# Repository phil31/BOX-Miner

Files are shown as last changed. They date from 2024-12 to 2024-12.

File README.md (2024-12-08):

## BOX Miner

#### The EKO-Miner is a stackable and rackable ASIC Bitcoin miner that utilizes hashcards. The hashcards are capable of mining Bitcoin by themselves or multiple. The concept of hashcards is highly scalable and offers a clean and streamlined approach to Bitcoin mining.

Miner Box Supports up to 3 ASIC Hashcards. An ATX PSU is required.

- Rackable miner boards based on specifics ASIC Hashboards, generic power supply and driven by an ESP32
- WIFI and ETHERNET connectivity
- TFT RGB LCD 172x320 display
- External standard ATX power supply
- Watercooling for quiet operation
- enclosure box dimensions: 200 x 200 x 140 mm

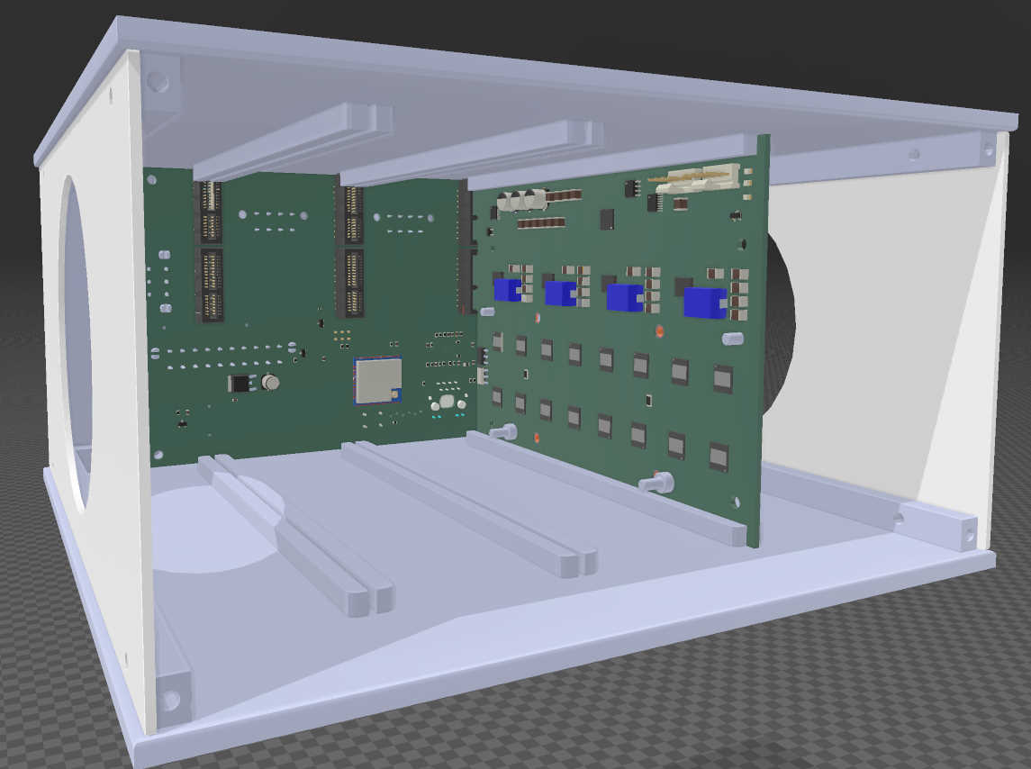
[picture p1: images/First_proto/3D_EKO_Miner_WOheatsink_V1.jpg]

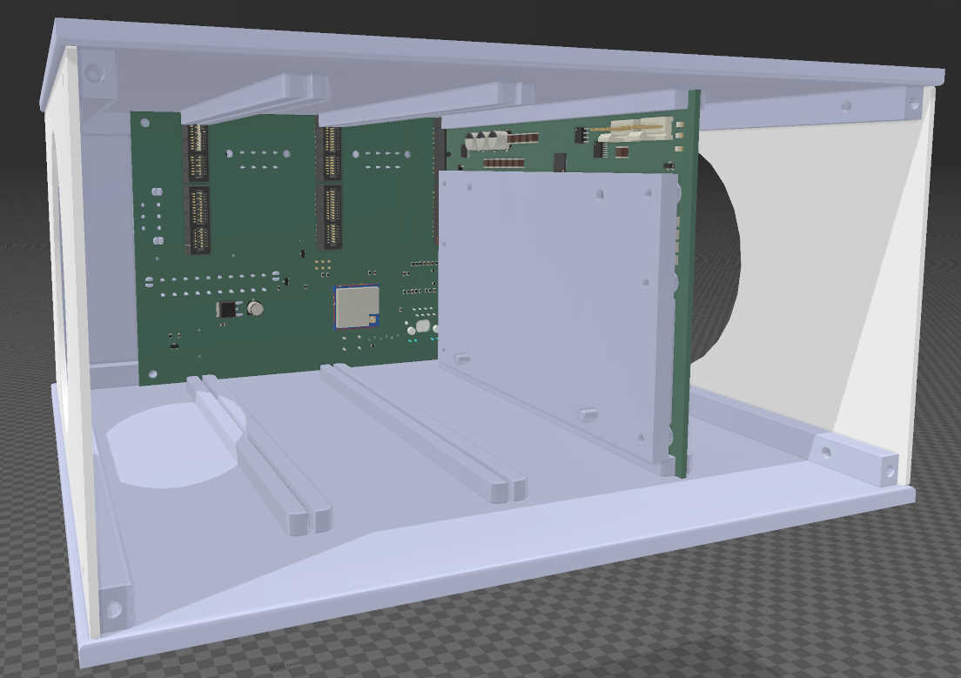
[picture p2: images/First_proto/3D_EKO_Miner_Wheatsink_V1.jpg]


#### Power board : 
- designed with TPS53667 / 5 Phases / 0.5 to 2.5V, up to 380Watts
- 6 layers PCB - Outer / Inner Copper Weight: 2 oz

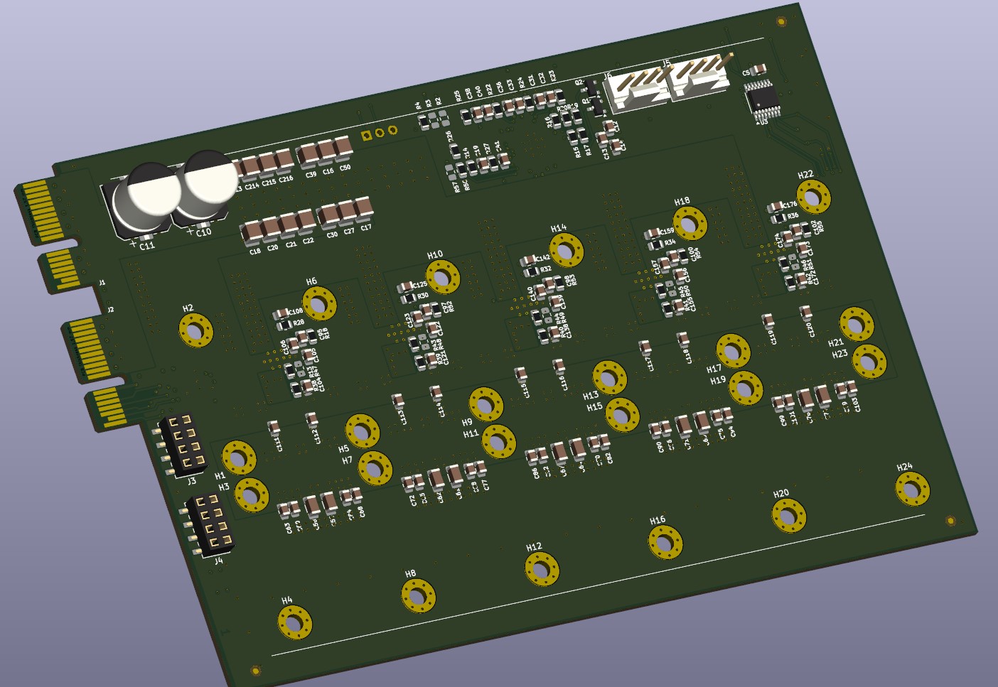
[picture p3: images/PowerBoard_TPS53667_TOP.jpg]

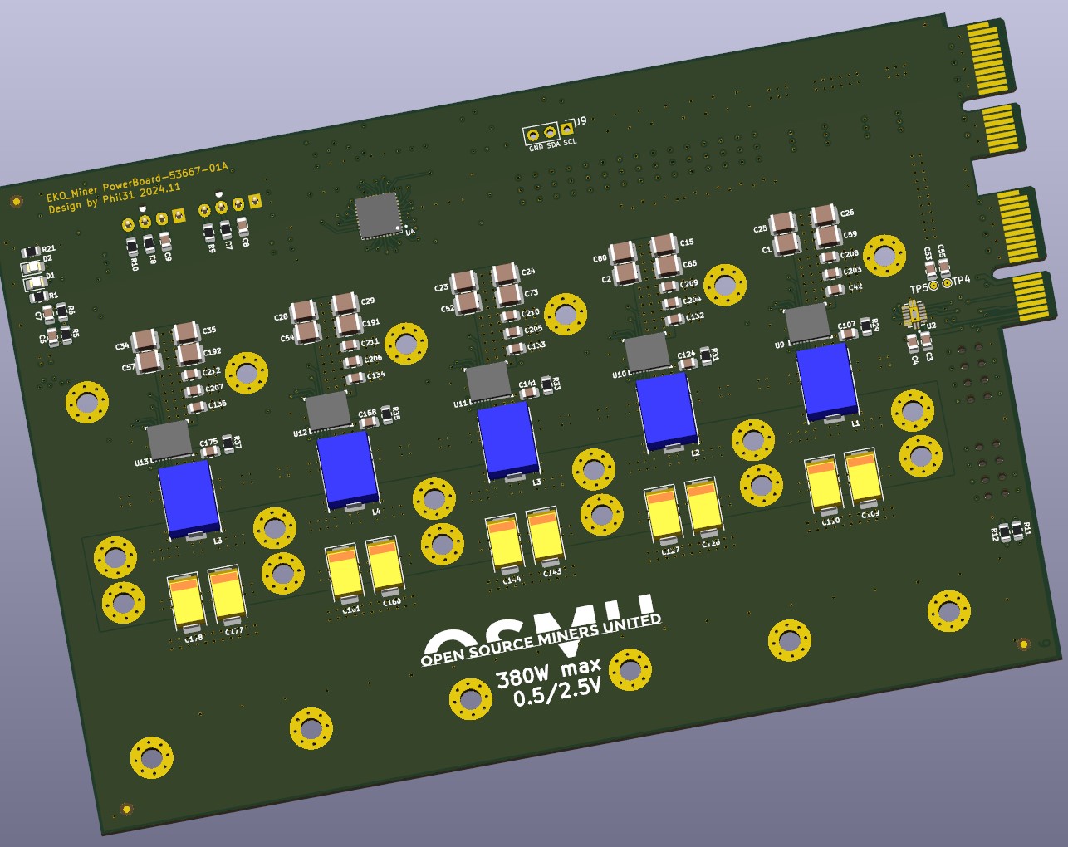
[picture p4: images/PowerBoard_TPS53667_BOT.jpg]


#### AsicBoards : 
- 16 x BM1366 : 8 TH/s - Efficiency 25J/TH
- 16 x BM1368 : 9.5 TH/s - Efficiency 18J/TH
- 10 x BM1370 : 12 TH/s - Efficiency 15J/TH

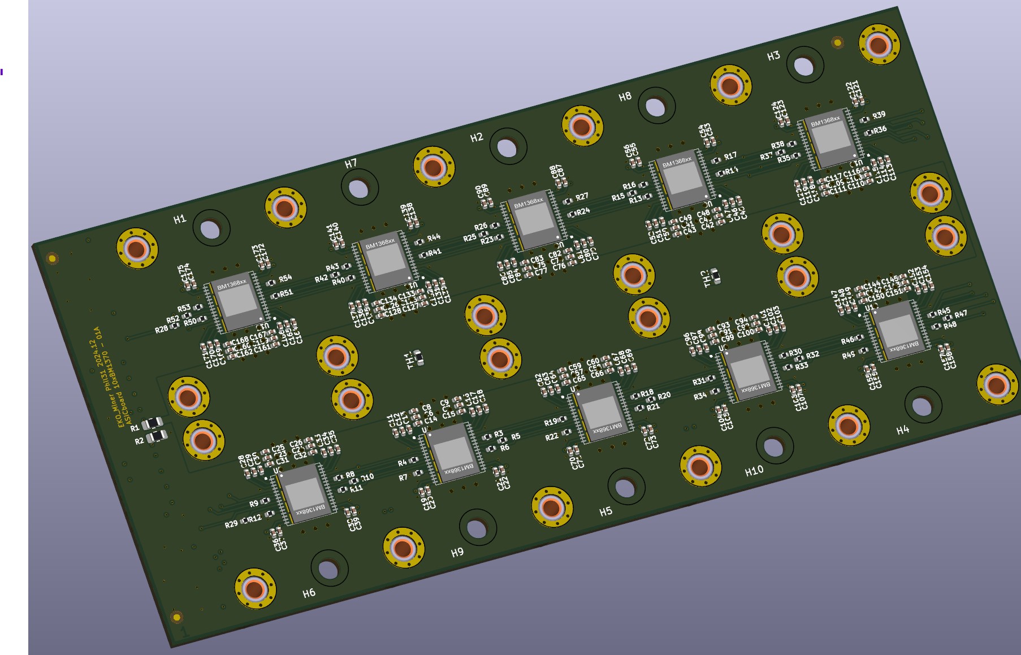
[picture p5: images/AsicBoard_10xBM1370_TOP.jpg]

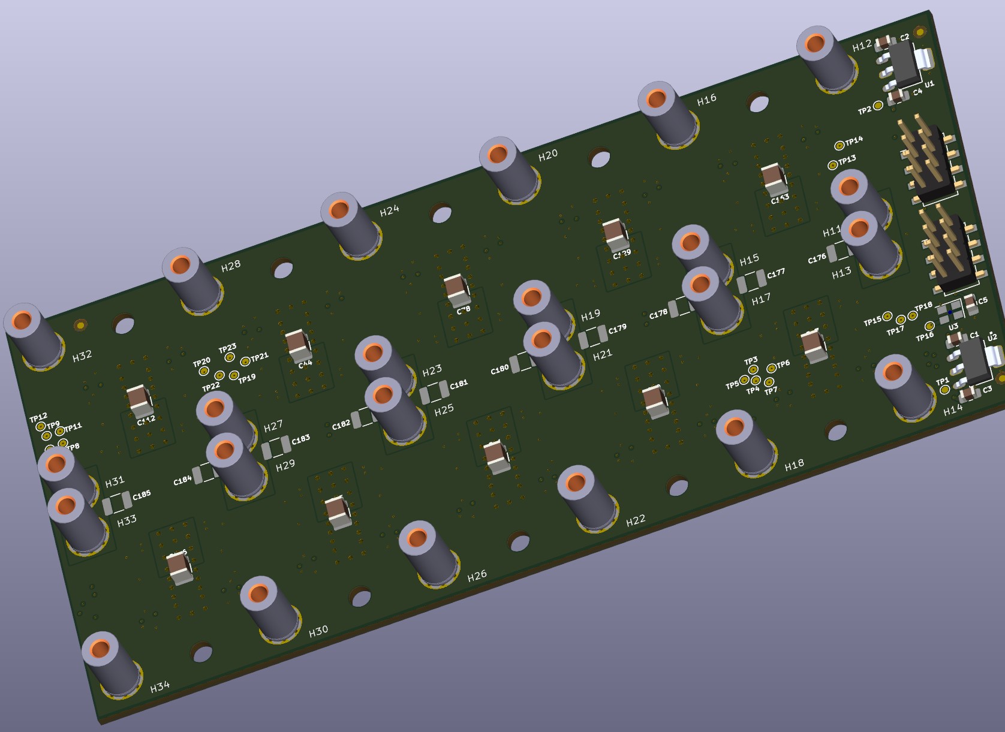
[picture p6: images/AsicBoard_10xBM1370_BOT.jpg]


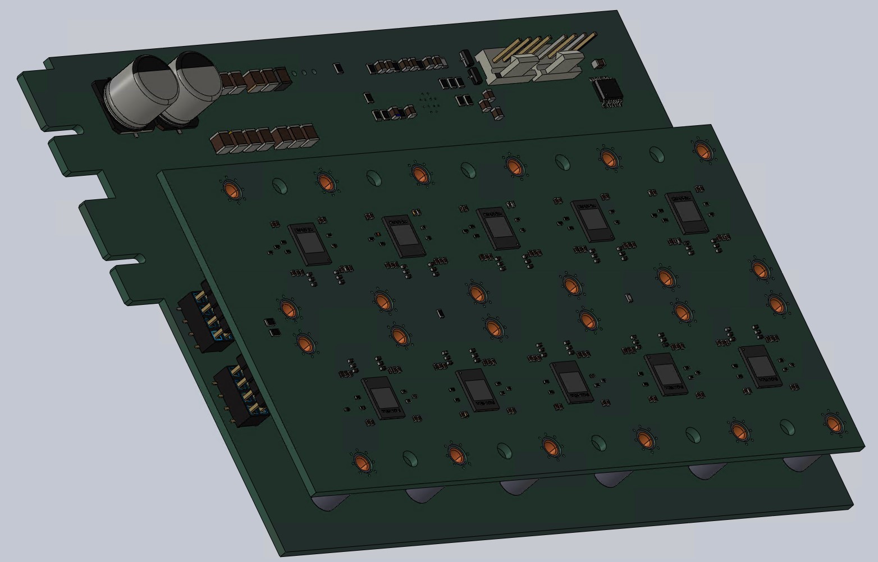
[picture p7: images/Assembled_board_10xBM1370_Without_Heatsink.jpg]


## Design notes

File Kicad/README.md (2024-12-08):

## BOX Miner

#### The EKO-Miner is a stackable and rackable ASIC Bitcoin miner that utilizes hashcards. The hashcards are capable of mining Bitcoin by themselves or multiple. The concept of hashcards is highly scalable and offers a clean and streamlined approach to Bitcoin mining.

#### 2024-12-07 : Theses boards are currently being validated

Power board : 
- designed with TPS53667 / 5 Phases / 0.5 to 2.5V, up to 300Watts

AsicBoards : 
- 16 x BM1366 : 8 TH/s - Efficiency 25J/TH
- 16 x BM1368 : 9.5 TH/s - Efficiency 18J/TH
- 10 x BM1370 : 10 TH/s - Efficiency 15J/TH

hashcard
hashcard
hashcard
hashcard
hashcard
hashcard

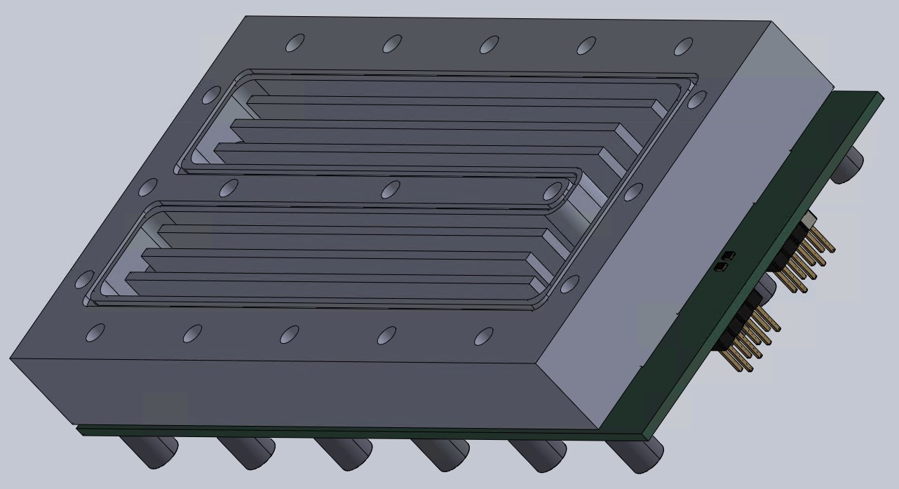
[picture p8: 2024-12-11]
3D/EKO_Miner Box AsicBoard/images/AsicBoard_10xBM1370_with_Watercooling3.jpg

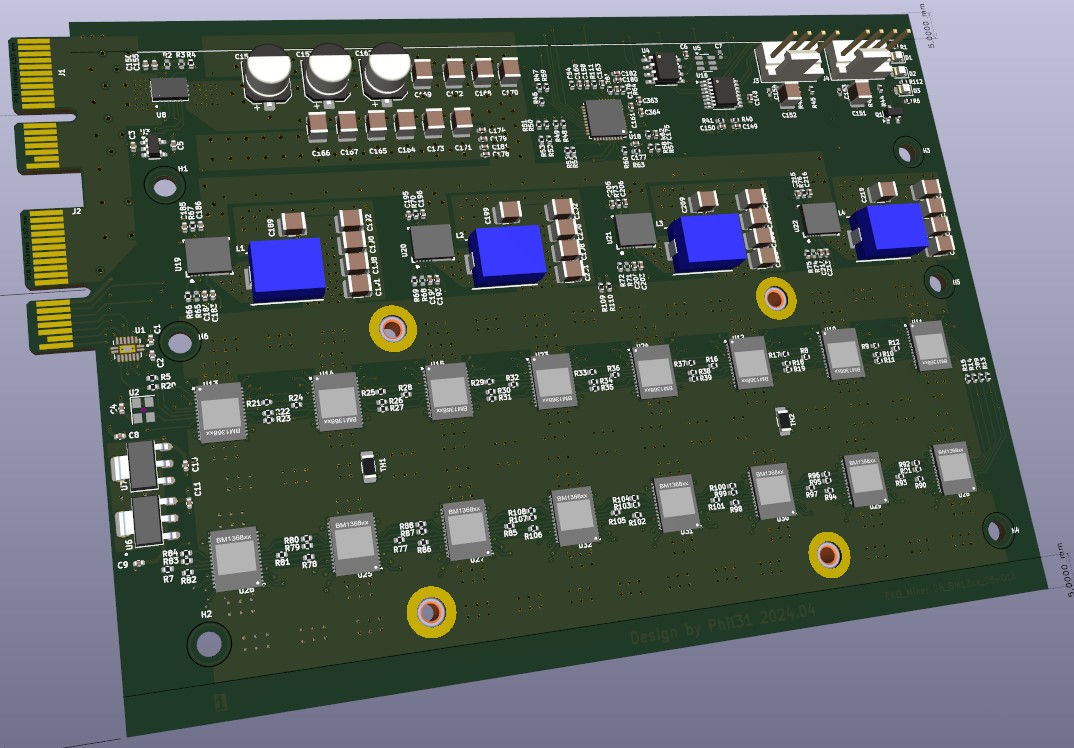
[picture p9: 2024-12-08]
images/First_proto/First_Proto_16xBM1366 T 3D.jpg

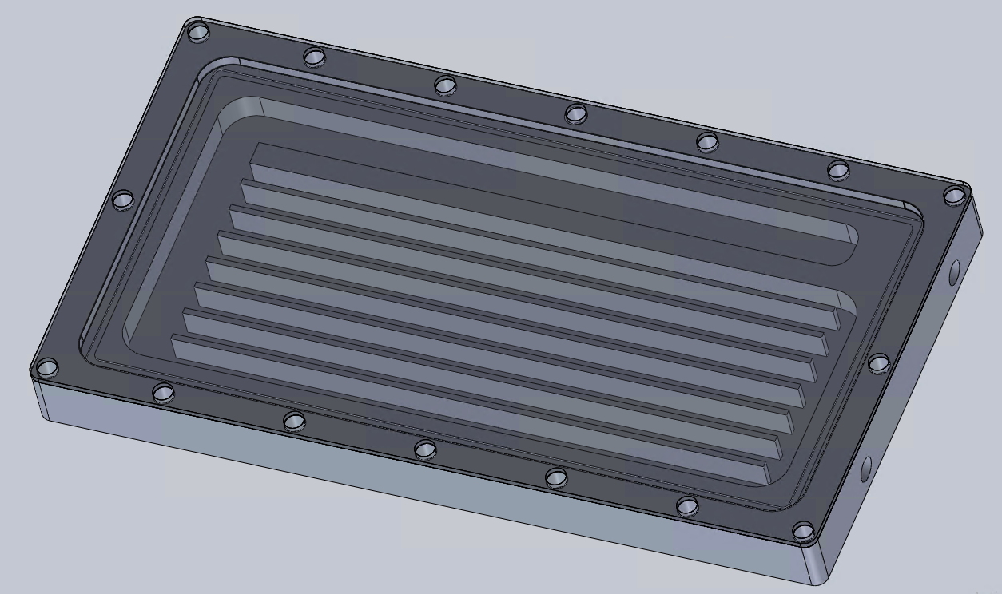
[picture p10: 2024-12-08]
images/WaterBloack_draft.png

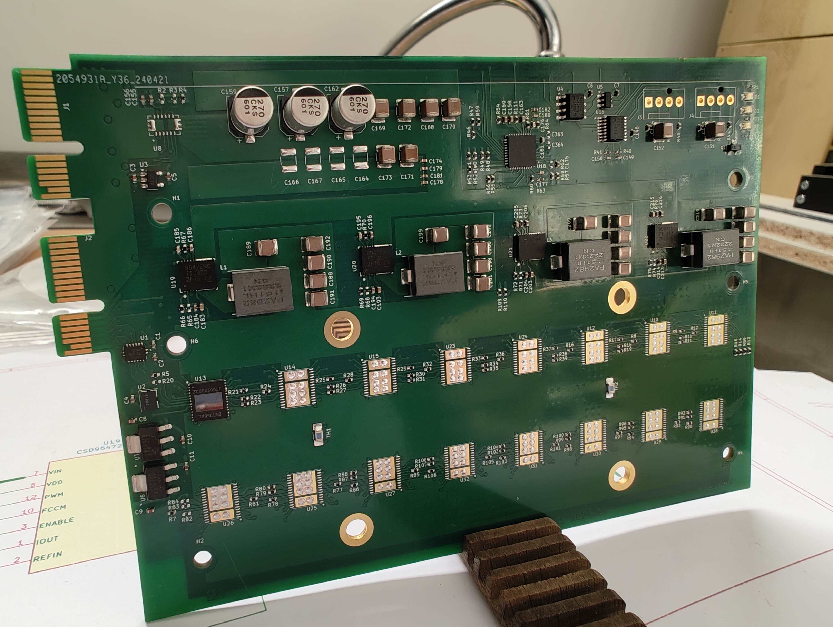
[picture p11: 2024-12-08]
images/First_proto/First_Proto_16xBM1366.jpg

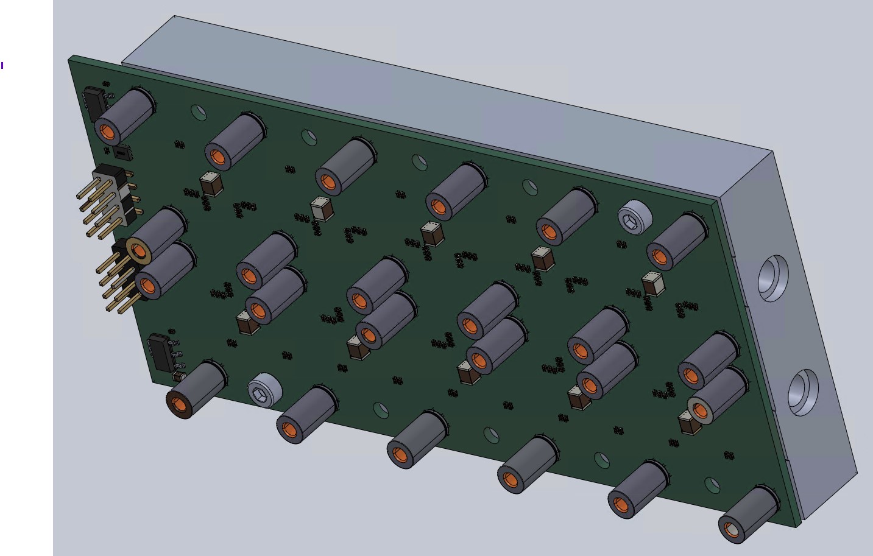
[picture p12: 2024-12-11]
3D/EKO_Miner Box AsicBoard/images/AsicBoard_10xBM1370_with_Watercooling2.jpg

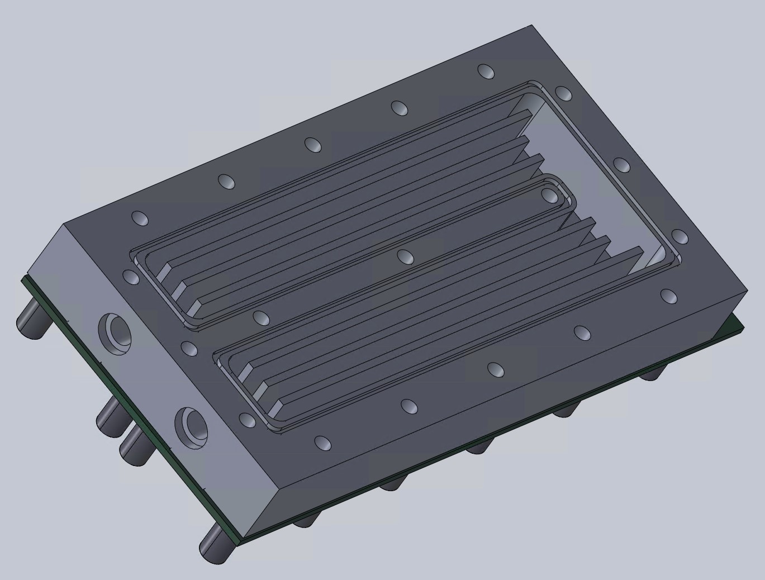
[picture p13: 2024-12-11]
3D/EKO_Miner Box AsicBoard/images/AsicBoard_10xBM1370_with_Watercooling.jpg

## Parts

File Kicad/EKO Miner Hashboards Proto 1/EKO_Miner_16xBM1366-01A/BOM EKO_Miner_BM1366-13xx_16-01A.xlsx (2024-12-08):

ligne | References | Empreinte | Quantité | designation | Fournisseur et rÃ©f
1 | R99,R10,R78,R27,R80,R12,R39,R8,R105,R37,R19,R107,R32,R91,R101,R104,R92,R26,R34,R9,R25,R98,R103,R83,R88,R18,R82,R38,R30,R96,R94,R33,R31,R108,R29,R13,R24,R95,R17,R93,R90,R77,R15,R16,R85,R23,R87,R100,R89,R102,R86,R79,R14,R11,R21,R84,R81,R22,R106,R97,R36,R28,R20,R35 | R_0402_1005Metric | 64 | 33 | 667-ERJ-2RKF33R0X | ok
2 | U19,U21,U20,U22 | CSD95472Q5MC | 4 | CSD95472Q5MC | 595-CSD95472Q5MC | ok
3 | C151,C172,C170,C168,C169,C173,C152,C171 | C_1210_3225Metric | 8 | 22uF | 187-CL32B226KAJNNNE (https://www.mouser.fr/ProductDetail/187-CL32B226KAJNNNE) | ok
4 | C195,C205,C180,C177,C215,C185 | C_0402_1005Metric | 6 | 1nF | 603-AC0402KR9BB102 (https://www.mouser.fr/ProductDetail/603-AC0402KR9BB102) | ok
5 | C174,C160,C158,C8,C9,C5,C163,C3,C11,C178,C10,C228,C224,C82,C139,C343,C133,C92,C278,C51,C344,C110,C321,C238,C98,C58,C332,C265,C357,C314,C341,C259,C59,C351,C273,C272,C276,C76,C122,C131,C346,C67,C86,C354,C45,C317,C120,C340,C243,C41,C135,C329,C275,C27,C355,C61,C99,C227,C89,C248,C115,C320,C323,C30,C109,C287,C105,C242,C80,C293,C102,C313,C325,C266,C17,C348,C281,C241,C53,C249,C28,C48,C118,C117,C300,C95,C345,C104,C262,C132,C270,C289,C75,C253,C277,C358,C72,C324,C257,C295,C143,C62,C146,C37,C46,C290,C347,C283,C84,C144,C330,C362,C31,C235,C47,C24,C32,C245,C291,C52,C274,C252,C264,C130,C359,C246,C225,C103,C83,C309,C342,C226,C236,C229,C280,C334,C223,C269,C297,C126,C34,C97,C306,C361,C138,C312,C70,C294,C147,C129,C232,C93,C240,C63,C29,C85,C50,C96,C119,C327,C230,C296,C338,C69,C256,C331,C261,C112,C33,C78,C66,C303,C307,C100,C282,C360,C315,C304,C260,C349,C337,C44,C49,C140,C121,C247,C106,C136,C123,C35,C87,C255,C328,C71,C38,C114,C311,C316,C134,C292,C42,C279,C19,C20,C286,C68,C239,C263,C16,C81,C18,C88,C231,C116,C333,C127,C308,C55,C113,C25,C137,C258,C326,C350,C65,C244,C310,C101,C298,C299,C79,C64,C21,C54,C36 | C_0402_1005Metric | 235 | 1uF | 81-GRM155R70G105MA2D | ok
6 | R49,R47 | R_0402_1005Metric | 2 | 24K3 | 71-CRCW0402-24.3K-E3 | ok
7 | C189,C211,C219,C220,C221,C192,C218,C201,C212,C200,C199,C208,C190,C210,C222,C191,C202,C188,C198,C209,C367,C365,C378,C371,C380,C370,C379,C372,C375,C376,C377,C368,C374,C373,C369,C366 | C_1210_3225Metric | 36 | 100uF | 187-CL32A107MQVNNNF | ok
8 | U29,U26,U31,U13,U11,U30,U32,U14,U12,U24,U15,U10,U28,U23,U25,U27 | BM1366 | 16 | BM1366_mode1
9 | C157,C162,C159 | CP_Elec_6.3x5.9 | 3 | 270uF | 667-EEE-FKC271XSP | ok
10 | R74,R75,R71,R69,R66,R65,R72,R68 | R_0402_1005Metric | 8 | 0R | 71-CRCW0402-0-E3 | ok
11 | R62 | R_0402_1005Metric | 1 | 35K
12 | C175 | C_0402_1005Metric | 1 | 2.2nF | 963-UMK105B7222MV-F | ok
13 | TH1,TH2 | R_1206_3216Metric_Pad1.30x1.75mm_HandSolder | 2 | PT1000
14 | R76,R67,R70,R73 | R_0402_1005Metric | 4 | 2R2 | 71-CRCW04022R20FKED | ok
15 | C153,C148,C186,C7,C4,C181,C2,C204,C6,C196,C184,C155,C1,C156,C194,C179,C206,C216,C154,C214,C22,C251,C267,C352,C90,C336,C124,C74,C285,C73,C56,C108,C233,C107,C91,C318,C319,C335,C39,C301,C353,C302,C250,C141,C268,C142,C234,C40,C284,C125,C57,C23 | C_0402_1005Metric | 52 | 100nF | 80-C0402C104K4RAUTO | ok
16 | R63 | R_0402_1005Metric | 1 | 121K | 71-CRCW0402-121K-E3 | ok
17 | R61 | R_0402_1005Metric | 1 | 2K55 | 603-RC0402FR-072K55L | ok
18 | C164,C167,C165,C166 | C_1210_3225Metric | 4 | 47uF 25V | 963-TMK325ABJ476MM-T | ok
19 | R56 | R_0402_1005Metric | 1 | 30K1 | 652-CR0402-FX3012GLF | ok
20 | R43,R42 | R_0402_1005Metric | 2 | 4.7K | 603-AC0402FR-074K7L | ok
21 | U4 | SOIC-8_3.9x4.9mm_P1.27mm | 1 | FM24C64B | 877-FM24C64B-G | ok
22 | R55 | R_0402_1005Metric | 1 | 33K2 | 652-CR0402-FX3322GLF | ok
23 | C176 | C_0402_1005Metric | 1 | 56pF | 81-GRM1555C1E560JA1D | ok
24 | L1,L4,L3,L2 | INDM1031X765N | 4 | 150nH | 673-PA2982.151HLT | ok
25 | U2 | Oscillator_SMD_Abracon_ASE-4Pin_3.2x2.5mm | 1 | 25MHz | 788-1602BI2218E25E | ok
26 | R41,R40 | R_0402_1005Metric | 2 | 1.6K | 652-CR0402FX-1601GLF | ok
27 | J2,J1 | BUS_PCIexpress_x1 | 2 | 10018784-10210TLF
28 | H6,H5,H1,H3,H4,H2 | MountingHole_3.2mm_M3_ISO7380 | 6 | MountingHole
29 | U8 | VQFN-14_REL0014B | 1 | INA745BIRELR
30 | C193,C213,C183,C203 | C_0402_1005Metric | 4 | 10uF | 81-GRM155R61A106ME1J | ok
31 | C149,C150 | C_0402_1005Metric | 2 | 100PF | 603-CC402KRNPO9BN101 | ok
32 | R2,R7,R5,R3,R4,R64 | R_0402_1005Metric | 6 | 10K | 603-AC0402FR-0710KL | ok
33 | R46,R48 | R_0402_1005Metric | 2 | 16K5 | 652-CR0402-FX1652GLF | ok
34 | R112,R6,R1 | R_0402_1005Metric | 3 | 180R | 652-CR0402FX-1800GLF | ok
35 | J4,J3 | FanPinHeader_1x04_P2.54mm_Vertical | 2 | Conn_01x04
36 | R110,R109 | R_0402_1005Metric | 2 | 51R 0.1% | 603-RT0402BRD0751RL | ok
37 | R58,R60 | R_0402_1005Metric | 2 | 20K | 603-RC0402FR-0720KL | ok
38 | D2,D1,D3 | LED_0805_2012Metric_Pad1.15x1.40mm_HandSolder | 3 | LED | 710-150080GS75000 | ok
39 | U6 | MCP1826S | 1 | MCP1826S-0802E_DB | MCP1826S-0802E/DB | ok
40 | R53 | R_0402_1005Metric | 1 | 39K2 | 603-RC0402FR-0739K2L | ok
41 | C182 | C_0402_1005Metric | 1 | 330nF | 187-CL05A334KQ5NNNC | ok
42 | U5 | SOT-23-6 | 1 | 24AA02E48T-E_OT | 579-24AA02E48T-E/OT | ok
43 | U3 | SOT-23-5 | 1 | MCP1824T-3302E/OT | 579-MCP1824T-3302EOT | ok
44 | R54,R111 | R_0402_1005Metric | 2 | 1R | 791-WR04W1R00FTL | ok
45 | C363,C364 | C_0402_1005Metric | 2 | 22pF | 810-C0402C0G1C220JBC | ok
46 | U7 | MCP1826S | 1 | MCP1826S-1802E_DB | 579-MCP1826S-1802EDB (https://www.mouser.fr/ProductDetail/579-MCP1826S-1802EDB) | ok
47 | U18 | QFN50P600X600X80-41N | 1 | TPS53647RHA | 595-TPS53647RTAR | ok
48 | R51 | R_0402_1005Metric | 1 | 150K | 791-WR04X1503FTL | ok
49 | C161 | C_0402_1005Metric | 1 | 100pF
50 | R45,R59,R44 | R_0402_1005Metric | 3 | 10k
51 | R50 | R_0402_1005Metric | 1 | 9K31 | 652-CR0402-FX9311GLF | ok
52 | U16 | QSOP-16_3.9x4.9mm_P0.635mm | 1 | MAX6615AEE_ | 700-MAX6615AEET | ok
53 | U1 | QFN50P350X250X80-17N | 1 | SN74AXC4T245BQB | 595-SN74AXC4T245BQBR | ok
54 | R52 | R_0402_1005Metric | 1 | 36K7
55 | R57 | R_0402_1005Metric | 1 | 4K32 | 603-AC0402FR-074K32L | ok
56 | Q1 | SOT-23 | 1 | BSS138
57 | C356,C77,C145,C254,C288,C305,C339,C271,C128,C207,C187,C60,C217,C237,C197,C94,C111,C26,C43,C322 | CP_EIA-7343-31_Kemet-D_Pad2.25x2.55mm_HandSolder | 20 | 330uF | 80-T591D337M006ATE25 | ok
 | entretoises 3mm : https://fr.rs-online.com/web/p/entretoises-pcb/1768149?gb=s | 9774030360R

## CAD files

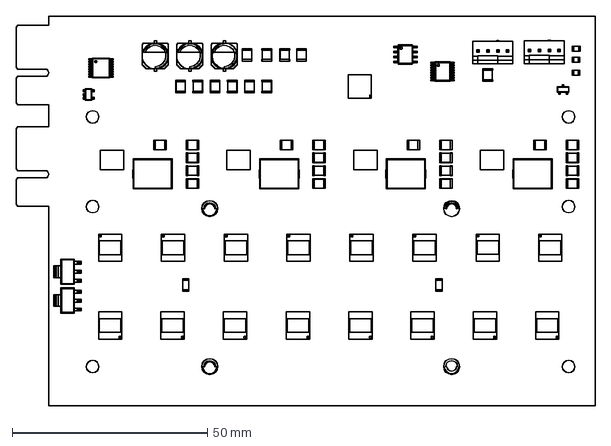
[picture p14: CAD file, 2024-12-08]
3D/EKO_Miner Box enclosure 3 lanes v1/DXF/EKO_Miner_BM1366 BM13xx-16 01A PCB full.DXF
148.4 x 99.8 mm

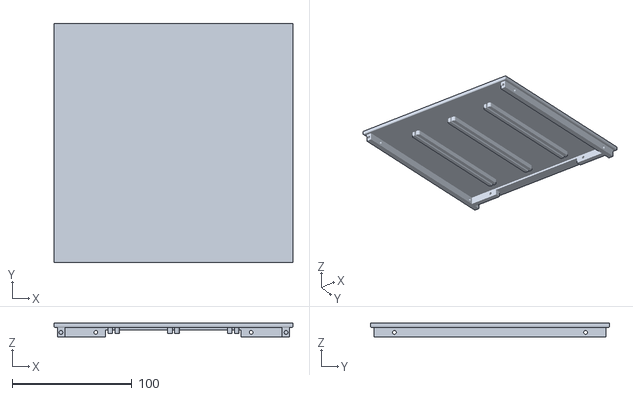
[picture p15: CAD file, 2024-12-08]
3D/EKO_Miner Box enclosure 3 lanes v1/exports/Assemblage EKO_Miner box V1 - Case - BottomTop 200x200-2.STL
200.0 x 200.0 x 12.0

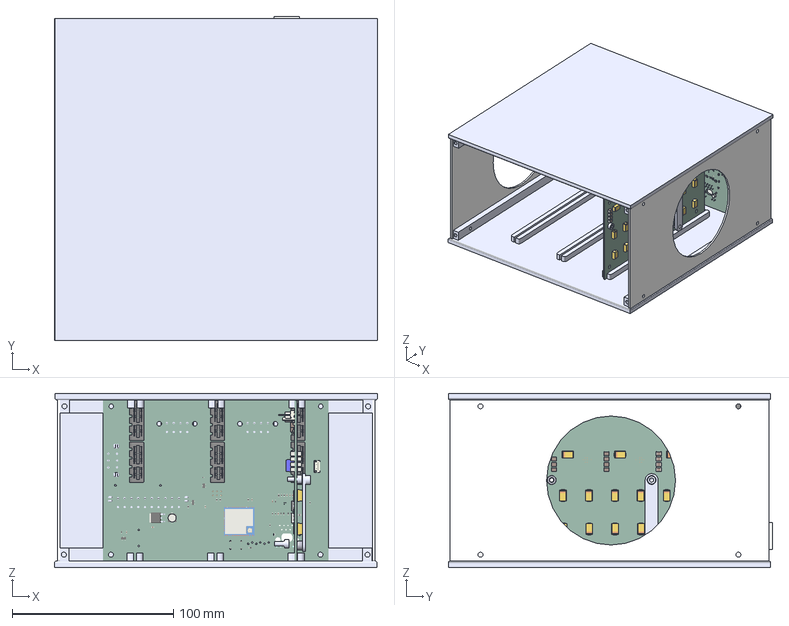
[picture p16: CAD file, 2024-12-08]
3D/EKO_Miner Box enclosure 3 lanes v1/exports/Assemblage EKO_Miner box V1 without Heatsink.3MF
200.4 x 201.3 x 108.0 mm

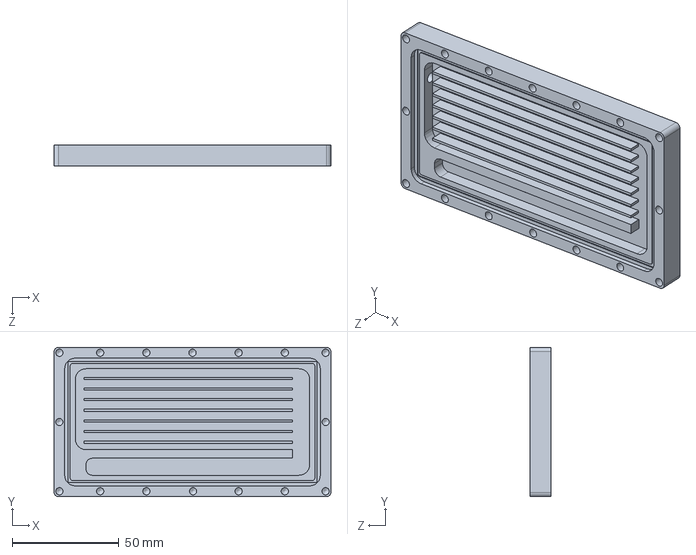
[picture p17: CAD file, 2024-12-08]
3D/EKO_Miner WaterBlock V1.0/Assemblage Watercooling C.SLDASM
130.0 x 70.0 x 10.0 mm

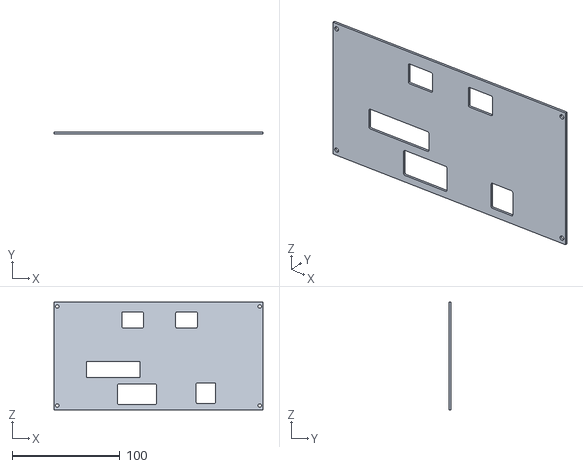
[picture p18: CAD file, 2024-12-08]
3D/EKO_Miner Box enclosure 3 lanes v1/exports/Assemblage EKO_Miner box V1 - Case - Rear-1.STL
194.0 x 1.60 x 100.0

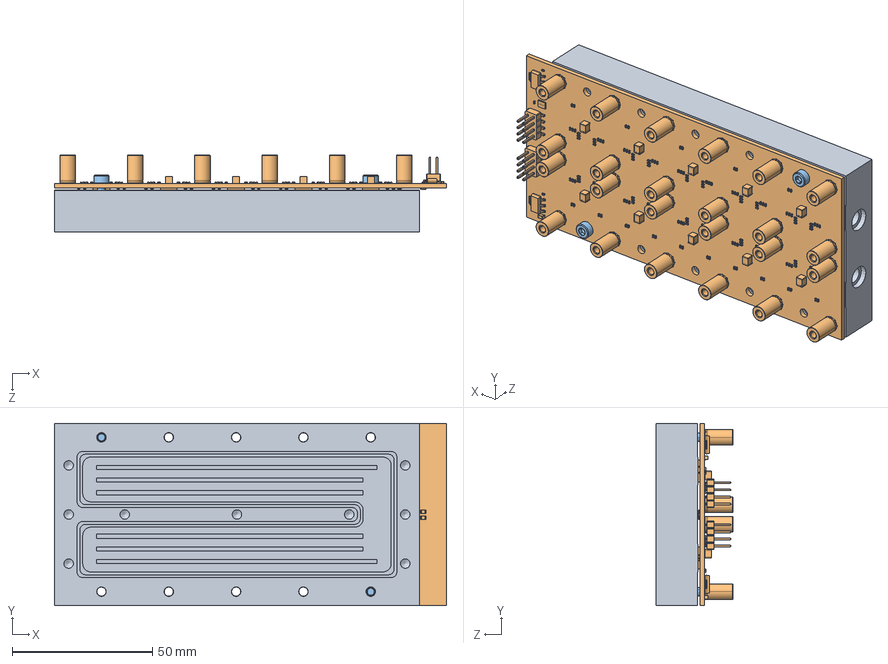
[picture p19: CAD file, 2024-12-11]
3D/EKO_Miner Box AsicBoard/EKO_Miner_AsicBoard-10xBM1370_With_Watercooling-01A.SLDASM
139.8 x 65.0 x 27.4 mm
EKO_Miner_AsicBoard-BM13xx Heatsink Version C 01A
EKO_Miner_AsicBoard-10xBM1370-01A
CHC3 M3x6mm x 2

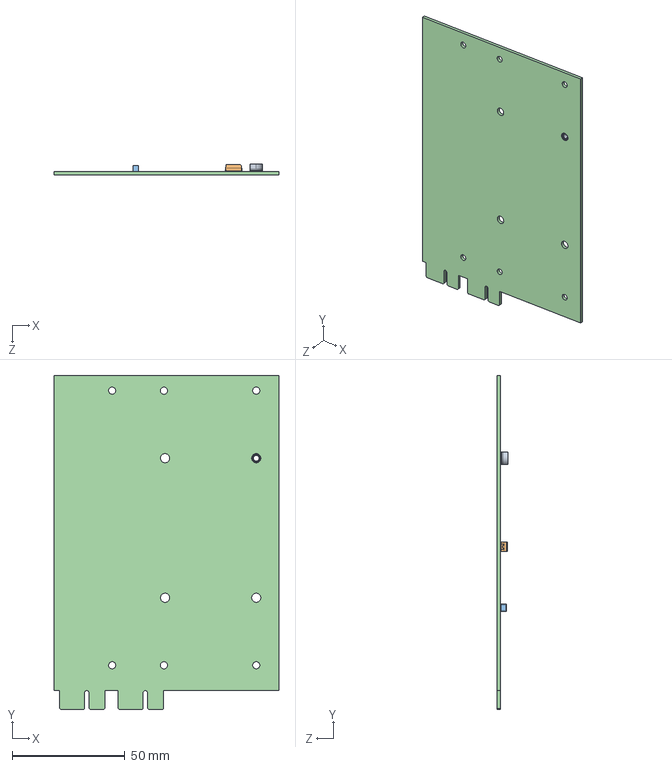
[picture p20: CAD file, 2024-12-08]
3D/EKO_Miner Box enclosure 3 lanes v1/Assemblage test support PCB.SLDASM
99.8 x 148.4 x 4.88 mm

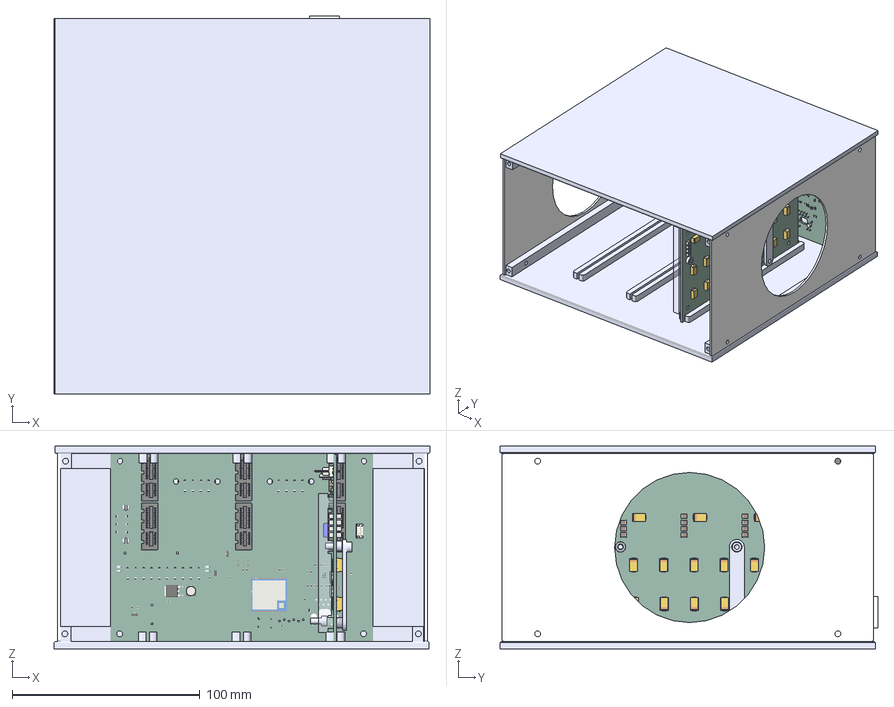
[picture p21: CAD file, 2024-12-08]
3D/EKO_Miner Box enclosure 3 lanes v1/exports/Assemblage EKO_Miner box V1 with Heatsink.3MF
200.4 x 201.3 x 108.0 mm

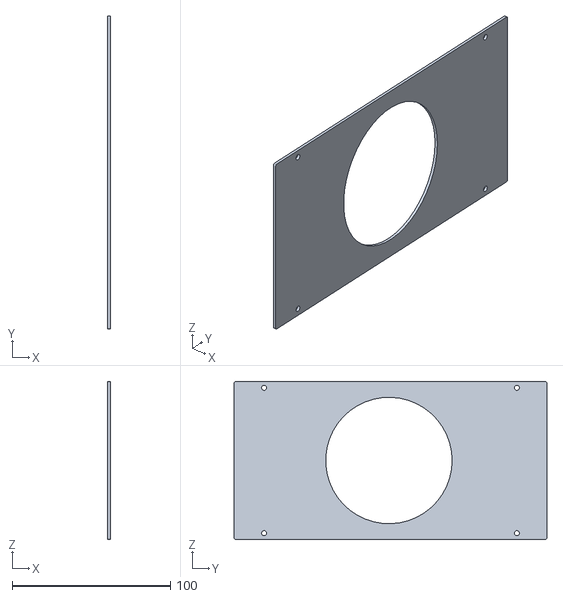
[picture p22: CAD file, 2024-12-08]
3D/EKO_Miner Box enclosure 3 lanes v1/exports/Assemblage EKO_Miner box V1 - Case - Coté-1.STL
1.60 x 198.0 x 100.0

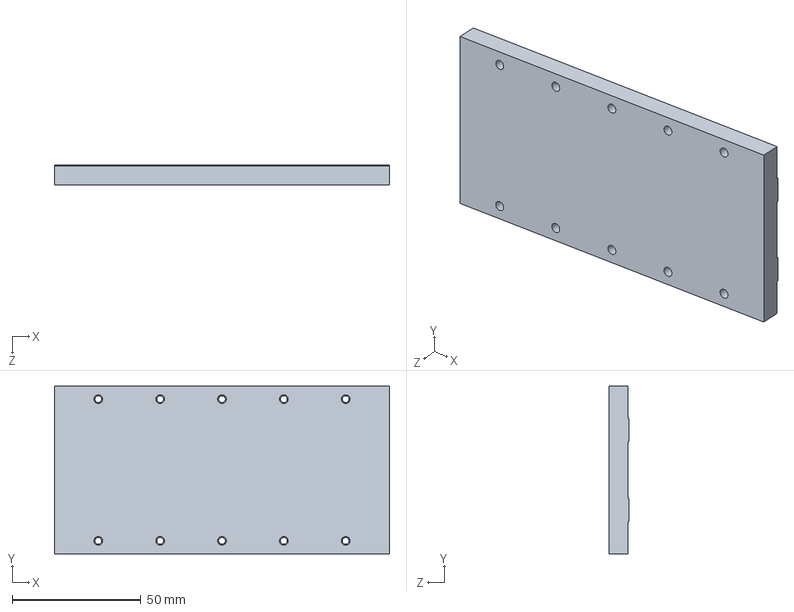
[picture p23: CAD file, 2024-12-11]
3D/EKO_Miner Box AsicBoard/EKO_Miner_AsicBoard-BM13xx Heatsink Base 03A.SLDPRT
130.0 x 65.0 x 7.80 mm

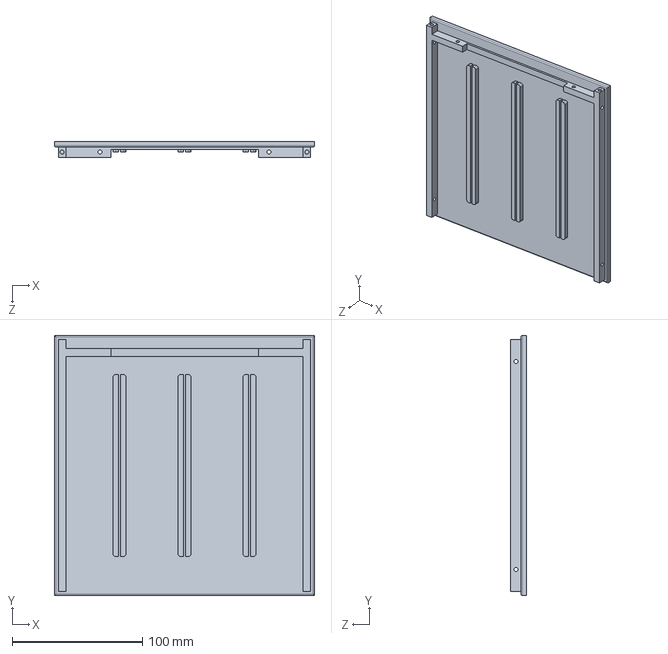
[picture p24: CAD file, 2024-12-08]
3D/EKO_Miner Box enclosure 3 lanes v1/Case - BottomTop 200x200.SLDPRT
200.0 x 200.0 x 12.0 mm

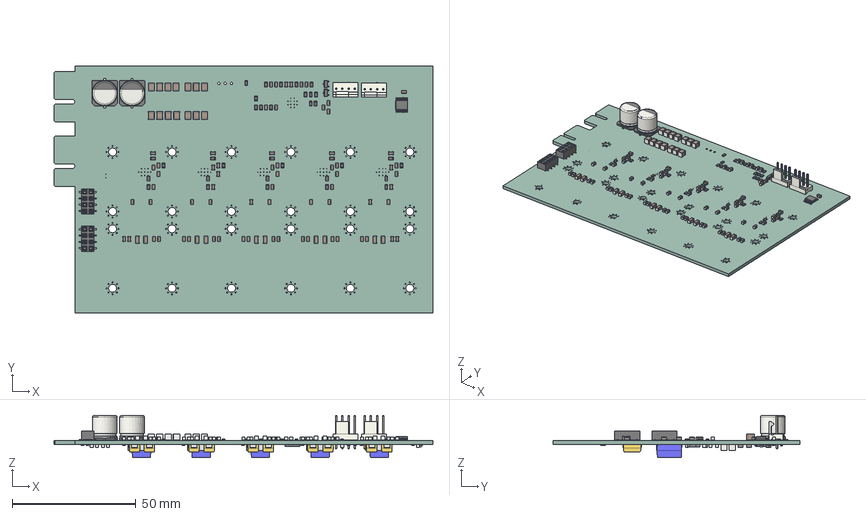
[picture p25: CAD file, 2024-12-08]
3D/EKO_Miner Box PowerBoard/EKO_Miner_PowerBoard_TPS53667_01A.step
153.0 x 99.8 x 17.0 mm
Fan_Pin_Header_Straight_1x04 x 2
C_0805_2012Metric x 95
R_0805_2012Metric x 49
C_1210_3225Metric x 34
C_1206_3216Metric x 10
QSOP_16_39x49mm_P0635mm
SOT_23 x 2
CP_Elec_10x10 x 2
Wuerth_WR-PHD_610008243021_SMD_2x04_P2.54mm_Vertical x 2
CP_EIA_7343_31_Kemet_D x 10
ASSEMBLY x 5
DMC0012A_ASM x 5
LED_0805_2012Metric x 2
DAC7822IRTAR
EKO_Miner_PowerBoard-53667_PCB

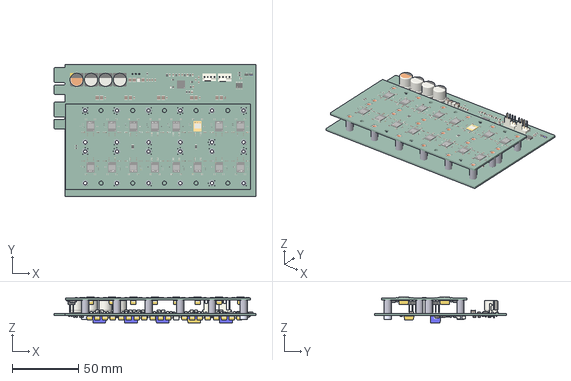
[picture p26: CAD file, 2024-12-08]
3D/EKO_Miner build 16xBM1366 V1.00.3MF
153.0 x 99.8 x 19.4 mm

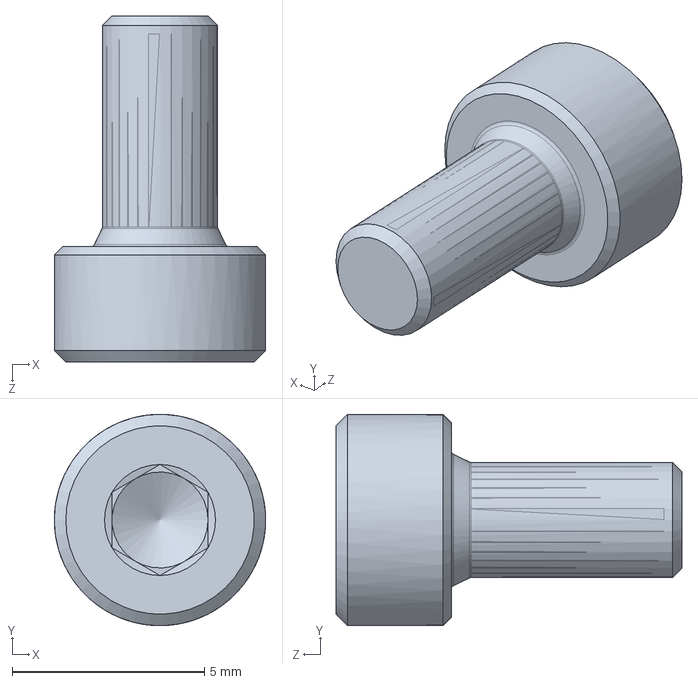
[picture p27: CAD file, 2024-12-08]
3D/quincaillerie/CHC3 M3x6mm.SLDPRT
5.50 x 5.50 x 9.00 mm

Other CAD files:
3D/EKO_Miner Box enclosure 3 lanes v1/exports/Assemblage EKO_Miner box V1 - Case - BottomTop 200x200-1.STL
3D/EKO_Miner WaterBlock V1.0/EKO_Miner WaterBlock V1.0 C.SLDPRT
EKO_Miner_ASIClib.sch/TMP1075NDRLR.step
3D/EKO_Miner Box AsicBoard/EKO_Miner_AsicBoard-16xBM1368-01A.step
3D/EKO_Miner Box AsicBoard/EKO_Miner_AsicBoard-10xBM1370-01A.SLDASM
3D/EKO_Miner Box AsicBoard/EKO_Miner_AsicBoard-10xBM1370-01A.step
3D/EKO_Miner Box AsicBoard/EKO_Miner_AsicBoard-16xBM1366-01A.SLDASM
3D/EKO_Miner Box AsicBoard/EKO_Miner_AsicBoard-16xBM1366-01A.step
3D/EKO_Miner Box AsicBoard/EKO_Miner_AsicBoard-16xBM13xx-01A Heatsink.SLDPRT
3D/EKO_Miner Box AsicBoard/EKO_Miner_AsicBoard-BM13xx Heatsink Base 01A.SLDDRW
3D/EKO_Miner Box AsicBoard/EKO_Miner_AsicBoard-BM13xx Heatsink Base 01A.SLDPRT
3D/EKO_Miner Box AsicBoard/EKO_Miner_AsicBoard-BM13xx Heatsink Base 02A.SLDPRT
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

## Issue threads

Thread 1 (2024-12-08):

wrong LCD bus

phil31, 2024-12-08:
the selected TFT screen require an SPI bus instead of I2C.
do not use it, use the original I2C screen

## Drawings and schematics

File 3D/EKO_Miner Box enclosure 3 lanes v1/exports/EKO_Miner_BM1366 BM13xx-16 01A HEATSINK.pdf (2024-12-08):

# Plan1@Esquisse3D1

Plan1@Esquisse3D1 | Plan1@Esquisse3D1

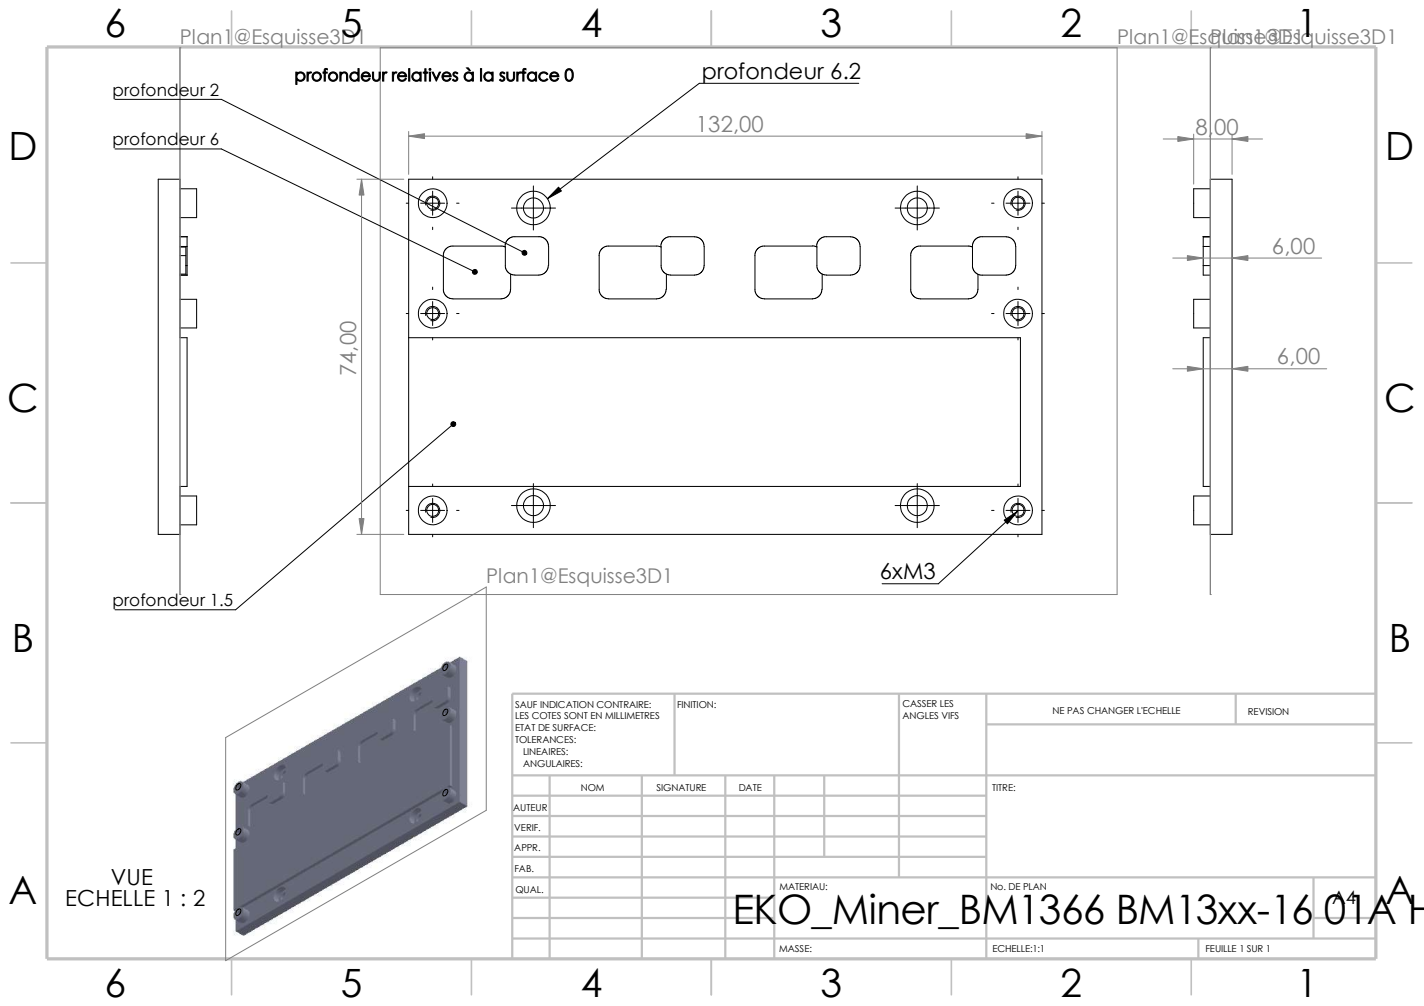
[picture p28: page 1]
Plan1@Esquisse3D1; ECHELLE:1:1; FEUILLE 1 SUR 1; MASSE:; REVISION; FINITION:; ANGLES VIFS; CASSER LES; EKO_Miner_BM1366 BM13xx-16 01A HEATSINK; VUE ECHELLE 1 : 2; profondeur 6; profondeur 2; profondeur 1.5; profondeur 6.2

profondeur relatives à la surface 0

SAUF INDICATION CONTRAIRE:
LES COTES SONT EN MILLIMETRES
ETAT DE SURFACE:
TOLERANCES:
LINEAIRES:
ANGULAIRES:

NE PAS CHANGER L'ECHELLE

NOM | SIGNATURE | DATE | | | | TITRE:

AUTEUR
VERIF.
APPR.

FAB.
QUAL. | | | | MATERIAU: | No. DE PLAN | A4

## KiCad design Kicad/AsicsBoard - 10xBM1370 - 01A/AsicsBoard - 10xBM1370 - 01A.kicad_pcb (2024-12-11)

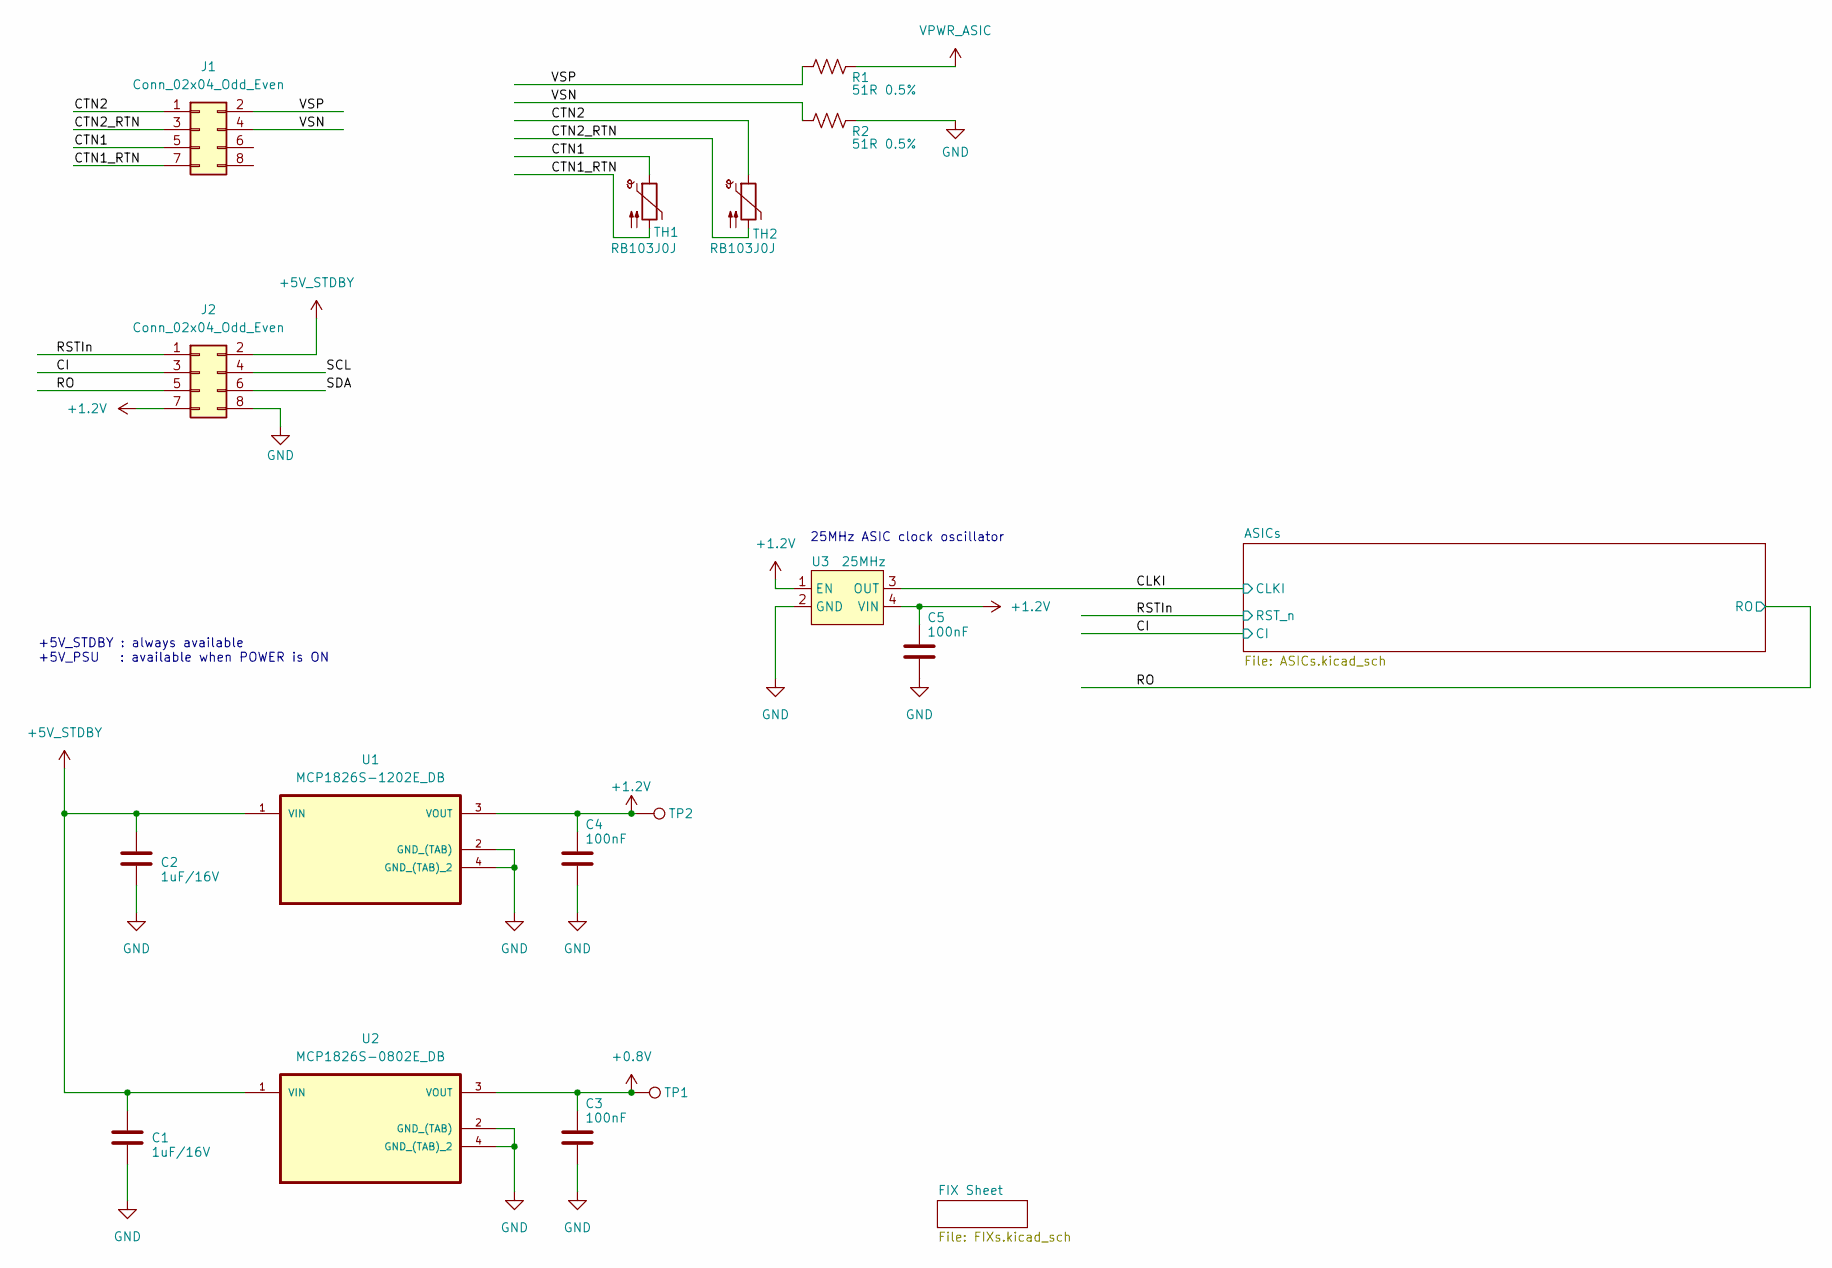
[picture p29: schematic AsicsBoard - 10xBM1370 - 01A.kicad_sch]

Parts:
C1, C2: 1uF/16V; C_0805_2012Metric_Pad1.18x1.45mm_HandSolder
C3, C4, C5: 100nF; C_0402_1005Metric
J1, J2: Conn_02x04_Odd_Even; PinHeader_2x04_P2.54mm_Vertical_SMD
R1, R2: 51R 0.5%; R_0805_2012Metric_Pad1.20x1.40mm_HandSolder
TH1, TH2: RB103J0J; R_0603_1608Metric
TP1, TP2: TestPoint; TestPoint_Pad_D1.0mm
U1: MCP1826S-1202E_DB; MCP1826S
U2: MCP1826S-0802E_DB; MCP1826S
U3: 25MHz; OSC_SMD_3.2x2.5mm

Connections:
+0.8V: C3.1, TP1.1, U2.3 (VOUT); also elsewhere on the board
+1.2V: C4.1, C5.1, J2.7, TP2.1, U1.3 (VOUT), U3.1 (EN), U3.4 (VIN); also elsewhere on the board
+5V_STDBY: C1.1, C2.1, J2.2, U1.1 (VIN), U2.1 (VIN)
/CI: J2.3; also elsewhere on the board
/CLKI: U3.3 (OUT); also elsewhere on the board
/CTN1: J1.5, TH1.1
/CTN1_RTN: J1.7, TH1.2
/CTN2: J1.1, TH2.1
/CTN2_RTN: J1.3, TH2.2
/RO: J2.5; also elsewhere on the board
/RSTIn: J2.1; also elsewhere on the board
/SCL: J2.4
/SDA: J2.6
/VSN: J1.4, R2.2
/VSP: J1.2, R1.2
GND: C1.2, C2.2, C3.2, C4.2, C5.2, J2.8, R2.1, U1.2 (GND_(TAB)), U1.4 (GND_(TAB)_2), U2.2 (GND_(TAB)), U2.4 (GND_(TAB)_2), U3.2 (GND); also elsewhere on the board
VPWR_ASIC: R1.1; also elsewhere on the board

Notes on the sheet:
+5V_STDBY : always available +5V_PSU : available when POWER is ON
25MHz ASIC clock oscillator

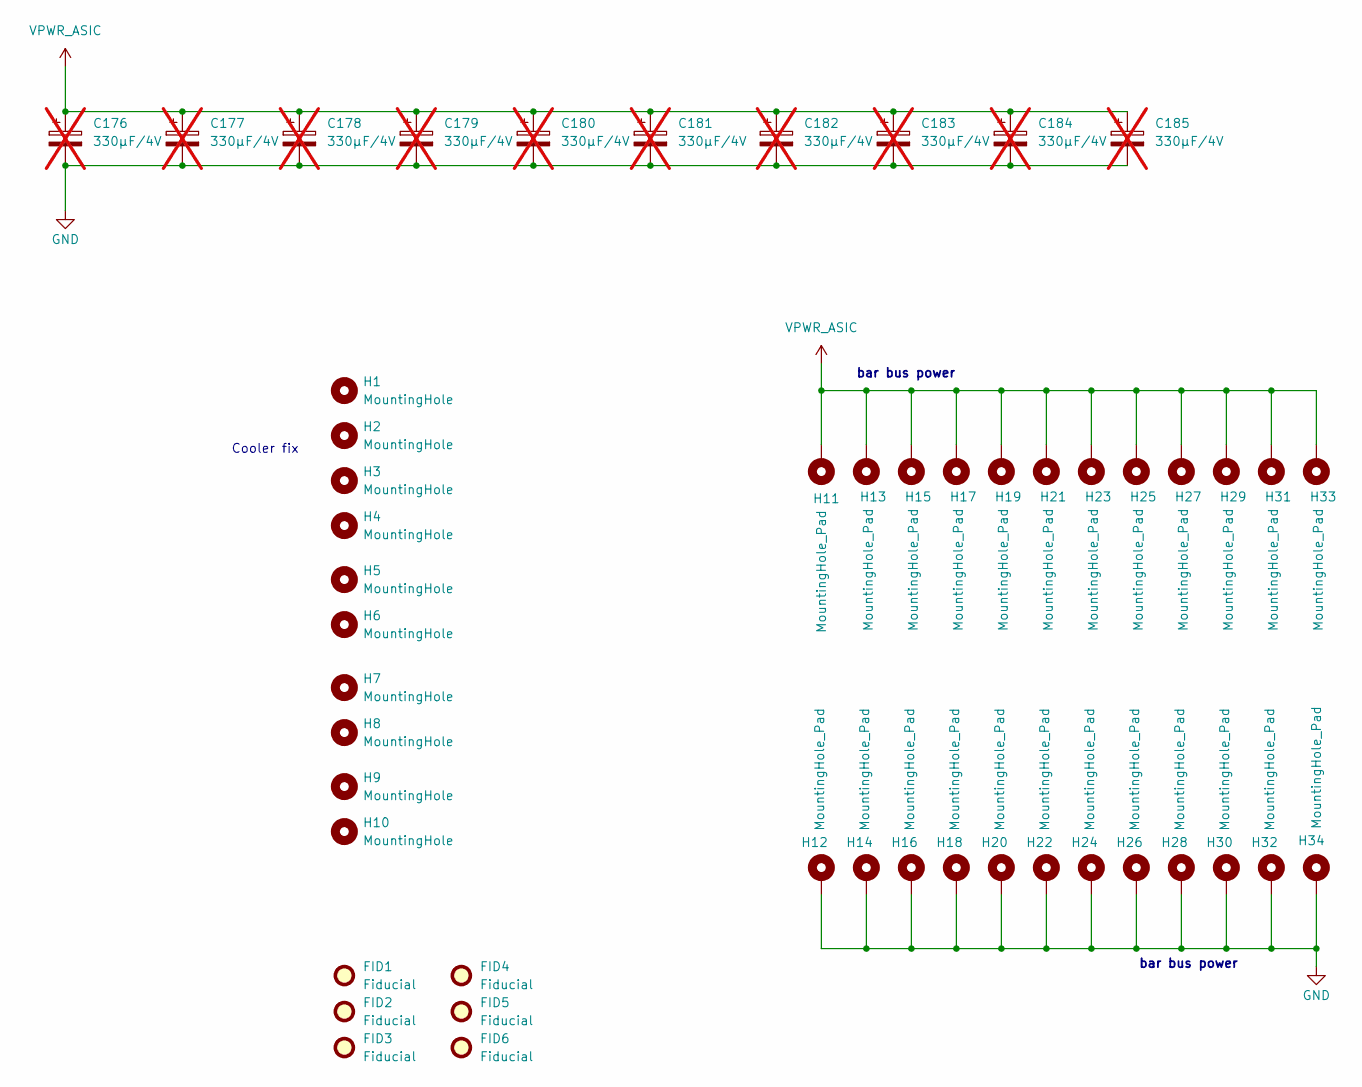
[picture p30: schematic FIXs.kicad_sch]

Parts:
C176, C177, C178, C179, C180, C181, C182, C183, C184, C185: 330µF/4V; C_1210_3225Metric; not fitted
FID1, FID2, FID3, FID4, FID5, FID6: Fiducial; Fiducial_1mm_Mask2mm
H1, H2, H3, H4, H5, H6, H7, H8, H9, H10: MountingHole; MountingHole_3.2mm_M3_ISO7380
H11, H12, H13, H14, H15, H16, H17, H18, H19, H20, H21, H22, H23, H24, H25, H26, H27, H28, H29, H30, H31, H32, H33, H34: MountingHole_Pad; SMTSO-M3-10ET

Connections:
GND: C176.2, C177.2, C178.2, C179.2, C180.2, C181.2, C182.2, C183.2, C184.2, C185.2, H12.1, H14.1, H16.1, H18.1, H20.1, H22.1, H24.1, H26.1, H28.1, H30.1, H32.1, H34.1; also elsewhere on the board
VPWR_ASIC: C176.1, C177.1, C178.1, C179.1, C180.1, C181.1, C182.1, C183.1, C184.1, C185.1, H11.1, H13.1, H15.1, H17.1, H19.1, H21.1, H23.1, H25.1, H27.1, H29.1, H31.1, H33.1; also elsewhere on the board

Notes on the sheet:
bar bus power
Cooler fix

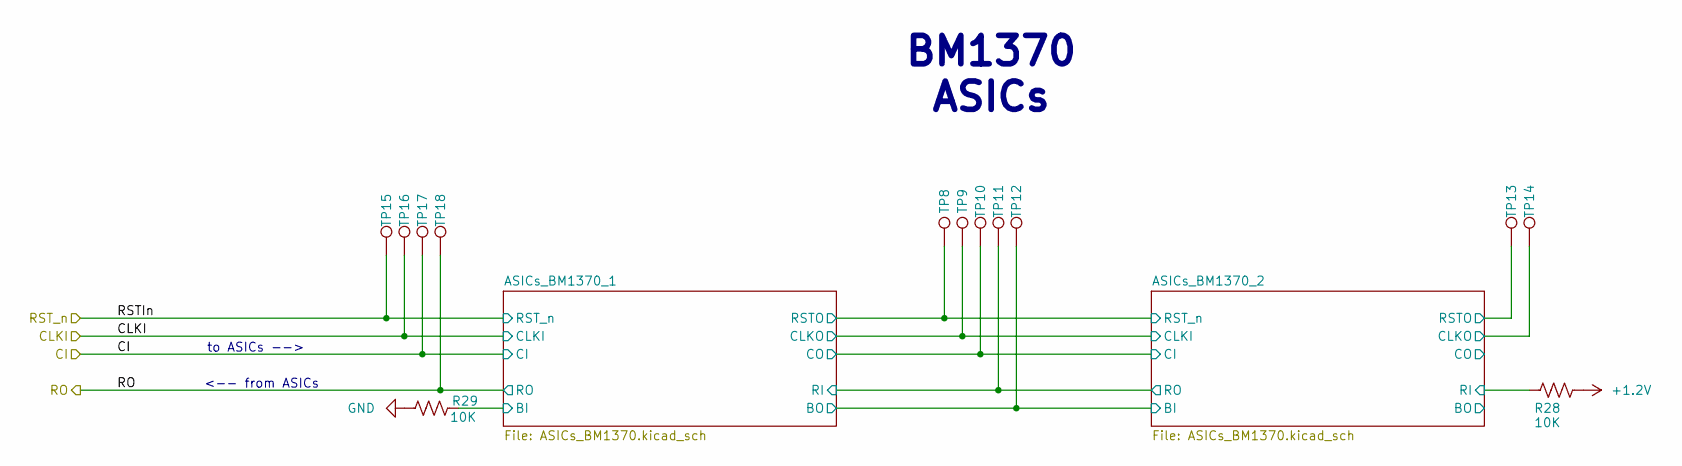
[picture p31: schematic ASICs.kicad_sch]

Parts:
R28, R29: 10K; R_0402_1005Metric
TP8, TP9, TP10, TP11, TP12, TP13, TP14, TP15, TP16, TP17, TP18: TestPoint; TestPoint_Pad_D1.0mm

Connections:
+1.2V: R28.1; also elsewhere on the board
/ASICs/ASICs_BM1370_1/BM1370-0/BI: R29.2; also elsewhere on the board
/ASICs/ASICs_BM1370_1/BM1370-4/BO: TP12.1; also elsewhere on the board
/ASICs/ASICs_BM1370_1/BM1370-4/CLKO: TP9.1; also elsewhere on the board
/ASICs/ASICs_BM1370_1/BM1370-4/CO: TP10.1; also elsewhere on the board
/ASICs/ASICs_BM1370_1/BM1370-4/RI: TP11.1; also elsewhere on the board
/ASICs/ASICs_BM1370_1/BM1370-4/RSTO_n: TP8.1; also elsewhere on the board
/ASICs/ASICs_BM1370_2/BM1370-4/CLKO: TP14.1; also elsewhere on the board
/ASICs/ASICs_BM1370_2/BM1370-4/RI: R28.2; also elsewhere on the board
/ASICs/ASICs_BM1370_2/BM1370-4/RSTO_n: TP13.1; also elsewhere on the board
/CI: TP17.1; also elsewhere on the board
/CLKI: TP16.1; also elsewhere on the board
/RO: TP18.1; also elsewhere on the board
/RSTIn: TP15.1; also elsewhere on the board
GND: R29.1; also elsewhere on the board

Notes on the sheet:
BM1370 ASICs
<-- from ASICs
to ASICs -->

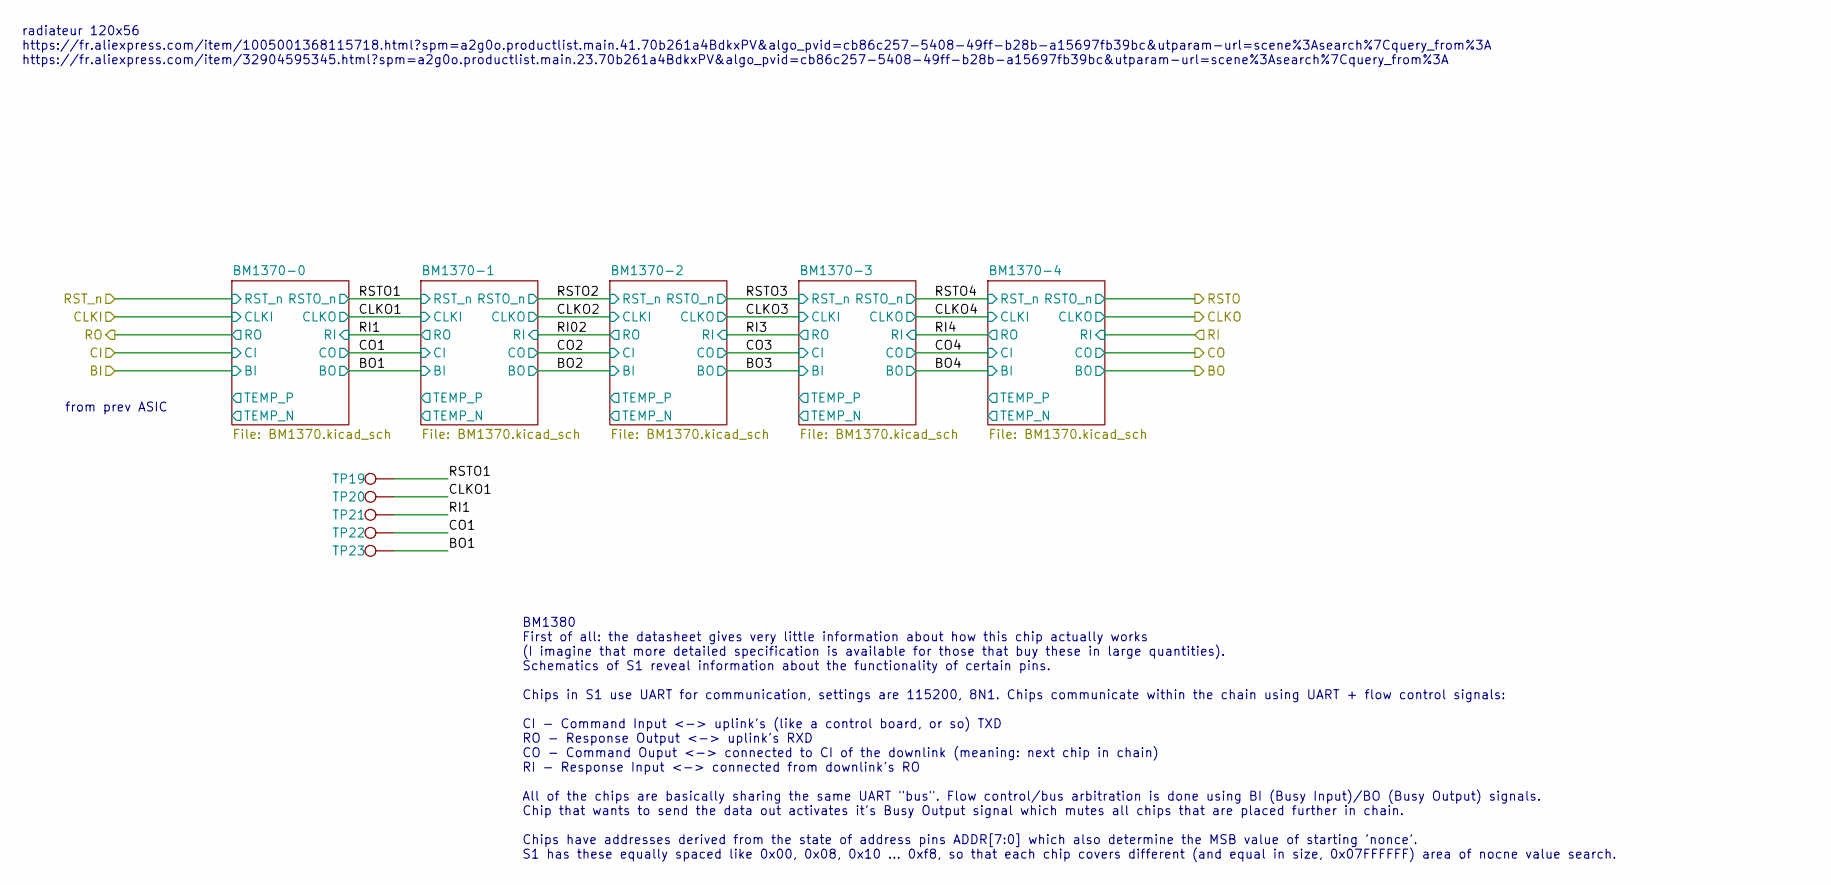
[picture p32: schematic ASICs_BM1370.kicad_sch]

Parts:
TP19, TP20, TP21, TP22, TP23: TestPoint; TestPoint_Pad_D1.0mm

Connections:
/ASICs/ASICs_BM1370_2/BO1: TP23.1; also elsewhere on the board
/ASICs/ASICs_BM1370_2/CLKO1: TP20.1; also elsewhere on the board
/ASICs/ASICs_BM1370_2/CO1: TP22.1; also elsewhere on the board
/ASICs/ASICs_BM1370_2/RI1: TP21.1; also elsewhere on the board
/ASICs/ASICs_BM1370_2/RSTO1: TP19.1; also elsewhere on the board

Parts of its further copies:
TP3, TP4, TP5, TP6, TP7: TestPoint; TestPoint_Pad_D1.0mm

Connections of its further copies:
/ASICs/ASICs_BM1370_1/BO1: TP7.1; also elsewhere on the board
/ASICs/ASICs_BM1370_1/CLKO1: TP4.1; also elsewhere on the board
/ASICs/ASICs_BM1370_1/CO1: TP6.1; also elsewhere on the board
/ASICs/ASICs_BM1370_1/RI1: TP5.1; also elsewhere on the board
/ASICs/ASICs_BM1370_1/RSTO1: TP3.1; also elsewhere on the board

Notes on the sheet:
from prev ASIC
BM1380 First of all: the datasheet gives very little information about how this chip actually works (I imagine that more detailed specification is available for those that buy these in large quantities). Schematics of S1 reveal information about the functionality of certain pins. Chips in S1 use UA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
radiateur 120x56 https://fr.aliexpress.com/item/1005001368115718.html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 https://fr.aliexpress.com/item/32904595345.html?spm=a2g0o.productlist.main.23.70b261a4BdkxPV&a…

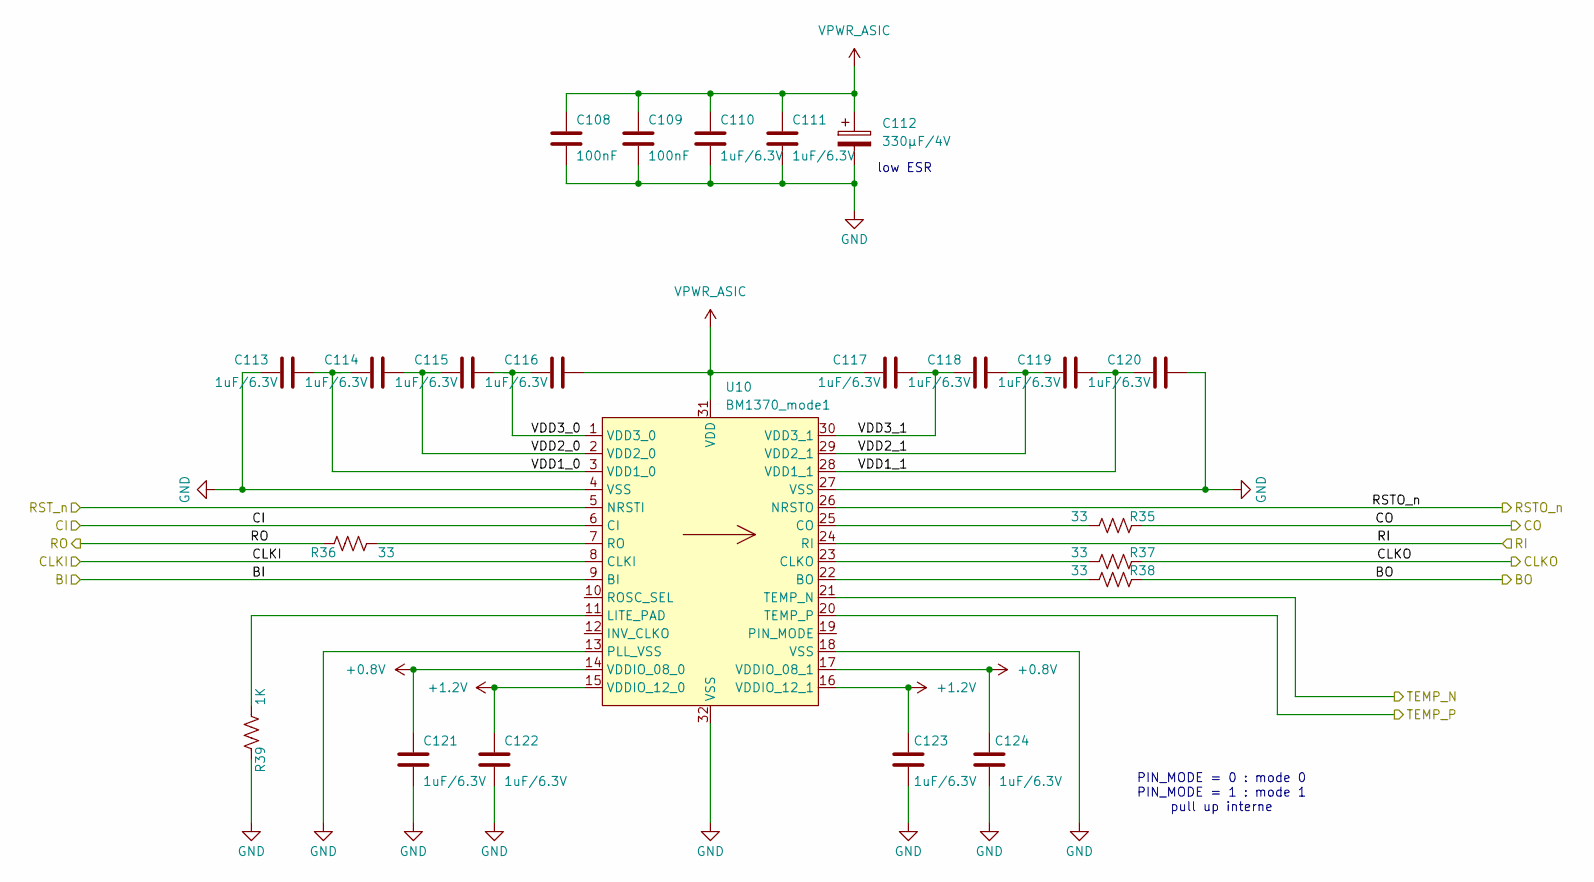
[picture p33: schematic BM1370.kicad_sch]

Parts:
C108, C109: 100nF; C_0402_1005Metric
C110, C111, C113, C114, C115, C116, C117, C118, C119, C120, C121, C122, C123, C124: 1uF/6.3V; C_0402_1005Metric
C112: 330µF/4V; C_1210_3225Metric
R35, R36, R37, R38: 33; R_0402_1005Metric
R39: 1K; R_0402_1005Metric
U10: BM1370_mode1; BM1370

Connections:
+0.8V: C121.1, C124.1, U10.14 (VDDIO_08_0), U10.17 (VDDIO_08_1); also elsewhere on the board
+1.2V: C122.1, C123.1, U10.15 (VDDIO_12_0), U10.16 (VDDIO_12_1); also elsewhere on the board
/ASICs/ASICs_BM1370_1/BM1370-4/BO: U10.9 (BI); also elsewhere on the board
/ASICs/ASICs_BM1370_1/BM1370-4/CLKO: U10.8 (CLKI); also elsewhere on the board
/ASICs/ASICs_BM1370_1/BM1370-4/CO: U10.6 (CI); also elsewhere on the board
/ASICs/ASICs_BM1370_1/BM1370-4/RI: R36.2; also elsewhere on the board
/ASICs/ASICs_BM1370_1/BM1370-4/RSTO_n: U10.5 (NRSTI); also elsewhere on the board
/ASICs/ASICs_BM1370_2/BM1370-0/TEMP_N: U10.21 (TEMP_N)
/ASICs/ASICs_BM1370_2/BM1370-0/TEMP_P: U10.20 (TEMP_P)
/ASICs/ASICs_BM1370_2/BM1370-0/VDD1_0: C113.2, C114.1, U10.3 (VDD1_0)
/ASICs/ASICs_BM1370_2/BM1370-0/VDD1_1: C119.2, C120.1, U10.28 (VDD1_1)
/ASICs/ASICs_BM1370_2/BM1370-0/VDD2_0: C114.2, C115.1, U10.2 (VDD2_0)
/ASICs/ASICs_BM1370_2/BM1370-0/VDD2_1: C118.2, C119.1, U10.29 (VDD2_1)
/ASICs/ASICs_BM1370_2/BM1370-0/VDD3_0: C115.2, C116.1, U10.1 (VDD3_0)
/ASICs/ASICs_BM1370_2/BM1370-0/VDD3_1: C117.2, C118.1, U10.30 (VDD3_1)
/ASICs/ASICs_BM1370_2/BO1: R38.2; also elsewhere on the board
/ASICs/ASICs_BM1370_2/CLKO1: R37.2; also elsewhere on the board
/ASICs/ASICs_BM1370_2/CO1: R35.2; also elsewhere on the board
/ASICs/ASICs_BM1370_2/RI1: U10.24 (RI); also elsewhere on the board
/ASICs/ASICs_BM1370_2/RSTO1: U10.26 (NRSTO); also elsewhere on the board
GND: C108.2, C109.2, C110.2, C111.2, C112.2, C113.1, C120.2, C121.2, C122.2, C123.2, C124.2, R39.2, U10.4 (VSS), U10.13 (PLL_VSS), U10.18 (VSS), U10.27 (VSS), U10.32 (VSS); also elsewhere on the board
unnamed: R38.1, U10.22 (BO)
unnamed: R37.1, U10.23 (CLKO)
unnamed: R35.1, U10.25 (CO)
unnamed: R39.1, U10.11 (LITE_PAD)
unnamed: R36.1, U10.7 (RO)
VPWR_ASIC: C108.1, C109.1, C110.1, C111.1, C112.1, C116.2, C117.1, U10.31 (VDD); also elsewhere on the board

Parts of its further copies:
C6, C7, C23, C24, C40, C41, C57, C58, C74, C75, C91, C92, C125, C126, C142, C143, C159, C160: 100nF; C_0402_1005Metric
C8, C9, C11, C12, C13, C14, C15, C16, C17, C18, C19, C20, C21, C22, C25, C26, C28, C29, C30, C31, C32, C33, C34, C35, C36, C37, C38, C39, C42, C43, C45, C46, C47, C48, C49, C50, C51, C52, C53, C54, C55, C56, C59, C60, C62, C63, C64, C65, C66, C67, C68, C69, C70, C71, C72, C73, C76, C77, C79, C80, C81, C82, C83, C84, C85, C86, C87, C88, C89, C90, C93, C94, C96, C97, C98, C99, C100, C101, C102, C103, C104, C105, C106, C107, C127, C128, C130, C131, C132, C133, C134, C135, C136, C137, C138, C139, C140, C141, C144, C145, C147, C148, C149, C150, C151, C152, C153, C154, C155, C156, C157, C158, C161, C162, C164, C165, C166, C167, C168, C169, C170, C171, C172, C173, C174, C175: 1uF/6.3V; C_0402_1005Metric
C10, C27, C44, C61, C78, C95, C129, C146, C163: 330µF/4V; C_1210_3225Metric
R3, R4, R5, R6, R8, R9, R10, R11, R13, R14, R15, R16, R18, R19, R20, R21, R23, R24, R25, R26, R30, R31, R32, R33, R40, R41, R42, R43, R45, R46, R47, R48, R50, R51, R52, R53: 33; R_0402_1005Metric
R7, R12, R17, R22, R27, R34, R44, R49, R54: 1K; R_0402_1005Metric
U4, U5, U6, U7, U8, U9, U11, U12, U13: BM1370_mode1; BM1370

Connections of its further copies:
+0.8V: C19.1, C22.1, C36.1, C39.1, C53.1, C56.1, C70.1, C73.1, C87.1, C90.1, C104.1, C107.1, C138.1, C141.1, C155.1, C158.1, C172.1, C175.1, U4.14 (VDDIO_08_0), U4.17 (VDDIO_08_1), U5.14 (VDDIO_08_0), U5.17 (VDDIO_08_1), U6.14 (VDDIO_08_0), U6.17 (VDDIO_08_1), U7.14 (VDDIO_08_0), U7.17 (VDDIO_08_1), U8.14 (VDDIO_08_0), U8.17 (VDDIO_08_1), U9.14 (VDDIO_08_0), U9.17 (VDDIO_08_1), U11.14 (VDDIO_08_0), U11.17 (VDDIO_08_1), U12.14 (VDDIO_08_0), U12.17 (VDDIO_08_1), U13.14 (VDDIO_08_0), U13.17 (VDDIO_08_1); also elsewhere on the board
+1.2V: C20.1, C21.1, C37.1, C38.1, C54.1, C55.1, C71.1, C72.1, C88.1, C89.1, C105.1, C106.1, C139.1, C140.1, C156.1, C157.1, C173.1, C174.1, U4.15 (VDDIO_12_0), U4.16 (VDDIO_12_1), U5.15 (VDDIO_12_0), U5.16 (VDDIO_12_1), U6.15 (VDDIO_12_0), U6.16 (VDDIO_12_1), U7.15 (VDDIO_12_0), U7.16 (VDDIO_12_1), U8.15 (VDDIO_12_0), U8.16 (VDDIO_12_1), U9.15 (VDDIO_12_0), U9.16 (VDDIO_12_1), U11.15 (VDDIO_12_0), U11.16 (VDDIO_12_1), U12.15 (VDDIO_12_0), U12.16 (VDDIO_12_1), U13.15 (VDDIO_12_0), U13.16 (VDDIO_12_1); also elsewhere on the board
/ASICs/ASICs_BM1370_1/BM1370-0/BI: U5.9 (BI); also elsewhere on the board
/ASICs/ASICs_BM1370_1/BM1370-0/TEMP_N: U5.21 (TEMP_N)
/ASICs/ASICs_BM1370_1/BM1370-0/TEMP_P: U5.20 (TEMP_P)
/ASICs/ASICs_BM1370_1/BM1370-0/VDD1_0: C28.2, C29.1, U5.3 (VDD1_0)
/ASICs/ASICs_BM1370_1/BM1370-0/VDD1_1: C34.2, C35.1, U5.28 (VDD1_1)
/ASICs/ASICs_BM1370_1/BM1370-0/VDD2_0: C29.2, C30.1, U5.2 (VDD2_0)
/ASICs/ASICs_BM1370_1/BM1370-0/VDD2_1: C33.2, C34.1, U5.29 (VDD2_1)
/ASICs/ASICs_BM1370_1/BM1370-0/VDD3_0: C30.2, C31.1, U5.1 (VDD3_0)
/ASICs/ASICs_BM1370_1/BM1370-0/VDD3_1: C32.2, C33.1, U5.30 (VDD3_1)
/ASICs/ASICs_BM1370_1/BM1370-1/TEMP_N: U4.21 (TEMP_N)
/ASICs/ASICs_BM1370_1/BM1370-1/TEMP_P: U4.20 (TEMP_P)
/ASICs/ASICs_BM1370_1/BM1370-1/VDD1_0: C11.2, C12.1, U4.3 (VDD1_0)
/ASICs/ASICs_BM1370_1/BM1370-1/VDD1_1: C17.2, C18.1, U4.28 (VDD1_1)
/ASICs/ASICs_BM1370_1/BM1370-1/VDD2_0: C12.2, C13.1, U4.2 (VDD2_0)
/ASICs/ASICs_BM1370_1/BM1370-1/VDD2_1: C16.2, C17.1, U4.29 (VDD2_1)
/ASICs/ASICs_BM1370_1/BM1370-1/VDD3_0: C13.2, C14.1, U4.1 (VDD3_0)
/ASICs/ASICs_BM1370_1/BM1370-1/VDD3_1: C15.2, C16.1, U4.30 (VDD3_1)
/ASICs/ASICs_BM1370_1/BM1370-2/TEMP_N: U7.21 (TEMP_N)
/ASICs/ASICs_BM1370_1/BM1370-2/TEMP_P: U7.20 (TEMP_P)
/ASICs/ASICs_BM1370_1/BM1370-2/VDD1_0: C62.2, C63.1, U7.3 (VDD1_0)
/ASICs/ASICs_BM1370_1/BM1370-2/VDD1_1: C68.2, C69.1, U7.28 (VDD1_1)
/ASICs/ASICs_BM1370_1/BM1370-2/VDD2_0: C63.2, C64.1, U7.2 (VDD2_0)
/ASICs/ASICs_BM1370_1/BM1370-2/VDD2_1: C67.2, C68.1, U7.29 (VDD2_1)
/ASICs/ASICs_BM1370_1/BM1370-2/VDD3_0: C64.2, C65.1, U7.1 (VDD3_0)
/ASICs/ASICs_BM1370_1/BM1370-2/VDD3_1: C66.2, C67.1, U7.30 (VDD3_1)
/ASICs/ASICs_BM1370_1/BM1370-3/TEMP_N: U9.21 (TEMP_N)
/ASICs/ASICs_BM1370_1/BM1370-3/TEMP_P: U9.20 (TEMP_P)
/ASICs/ASICs_BM1370_1/BM1370-3/VDD1_0: C96.2, C97.1, U9.3 (VDD1_0)
/ASICs/ASICs_BM1370_1/BM1370-3/VDD1_1: C102.2, C103.1, U9.28 (VDD1_1)
/ASICs/ASICs_BM1370_1/BM1370-3/VDD2_0: C97.2, C98.1, U9.2 (VDD2_0)
/ASICs/ASICs_BM1370_1/BM1370-3/VDD2_1: C101.2, C102.1, U9.29 (VDD2_1)
/ASICs/ASICs_BM1370_1/BM1370-3/VDD3_0: C98.2, C99.1, U9.1 (VDD3_0)
/ASICs/ASICs_BM1370_1/BM1370-3/VDD3_1: C100.2, C101.1, U9.30 (VDD3_1)
/ASICs/ASICs_BM1370_1/BM1370-4/BO: R48.2; also elsewhere on the board
/ASICs/ASICs_BM1370_1/BM1370-4/CLKO: R47.2; also elsewhere on the board
/ASICs/ASICs_BM1370_1/BM1370-4/CO: R45.2; also elsewhere on the board
/ASICs/ASICs_BM1370_1/BM1370-4/RI: U12.24 (RI); also elsewhere on the board
/ASICs/ASICs_BM1370_1/BM1370-4/RSTO_n: U12.26 (NRSTO); also elsewhere on the board
/ASICs/ASICs_BM1370_1/BM1370-4/TEMP_N: U12.21 (TEMP_N)
/ASICs/ASICs_BM1370_1/BM1370-4/TEMP_P: U12.20 (TEMP_P)
/ASICs/ASICs_BM1370_1/BM1370-4/VDD1_0: C147.2, C148.1, U12.3 (VDD1_0)
/ASICs/ASICs_BM1370_1/BM1370-4/VDD1_1: C153.2, C154.1, U12.28 (VDD1_1)
/ASICs/ASICs_BM1370_1/BM1370-4/VDD2_0: C148.2, C149.1, U12.2 (VDD2_0)
/ASICs/ASICs_BM1370_1/BM1370-4/VDD2_1: C152.2, C153.1, U12.29 (VDD2_1)
/ASICs/ASICs_BM1370_1/BM1370-4/VDD3_0: C149.2, C150.1, U12.1 (VDD3_0)
/ASICs/ASICs_BM1370_1/BM1370-4/VDD3_1: C151.2, C152.1, U12.30 (VDD3_1)
/ASICs/ASICs_BM1370_1/BO1: R11.2, U4.9 (BI); also elsewhere on the board
/ASICs/ASICs_BM1370_1/BO2: R6.2, U7.9 (BI)
/ASICs/ASICs_BM1370_1/BO3: R21.2, U9.9 (BI)
/ASICs/ASICs_BM1370_1/BO4: R33.2, U12.9 (BI)
/ASICs/ASICs_BM1370_1/CLKO1: R10.2, U4.8 (CLKI); also elsewhere on the board
/ASICs/ASICs_BM1370_1/CLKO2: R5.2, U7.8 (CLKI)
/ASICs/ASICs_BM1370_1/CLKO3: R20.2, U9.8 (CLKI)
/ASICs/ASICs_BM1370_1/CLKO4: R32.2, U12.8 (CLKI)
/ASICs/ASICs_BM1370_1/CO1: R8.2, U4.6 (CI); also elsewhere on the board
/ASICs/ASICs_BM1370_1/CO2: R3.2, U7.6 (CI)
/ASICs/ASICs_BM1370_1/CO3: R18.2, U9.6 (CI)
/ASICs/ASICs_BM1370_1/CO4: R30.2, U12.6 (CI)
/ASICs/ASICs_BM1370_1/RI1: R4.2, U5.24 (RI); also elsewhere on the board
/ASICs/ASICs_BM1370_1/RI02: R19.2, U4.24 (RI)
/ASICs/ASICs_BM1370_1/RI3: R31.2, U7.24 (RI)
/ASICs/ASICs_BM1370_1/RI4: R46.2, U9.24 (RI)
/ASICs/ASICs_BM1370_1/RSTO1: U4.5 (NRSTI), U5.26 (NRSTO); also elsewhere on the board
/ASICs/ASICs_BM1370_1/RSTO2: U4.26 (NRSTO), U7.5 (NRSTI)
/ASICs/ASICs_BM1370_1/RSTO3: U7.26 (NRSTO), U9.5 (NRSTI)
/ASICs/ASICs_BM1370_1/RSTO4: U9.26 (NRSTO), U12.5 (NRSTI)
/ASICs/ASICs_BM1370_2/BM1370-1/TEMP_N: U6.21 (TEMP_N)
/ASICs/ASICs_BM1370_2/BM1370-1/TEMP_P: U6.20 (TEMP_P)
/ASICs/ASICs_BM1370_2/BM1370-1/VDD1_0: C45.2, C46.1, U6.3 (VDD1_0)
/ASICs/ASICs_BM1370_2/BM1370-1/VDD1_1: C51.2, C52.1, U6.28 (VDD1_1)
/ASICs/ASICs_BM1370_2/BM1370-1/VDD2_0: C46.2, C47.1, U6.2 (VDD2_0)
/ASICs/ASICs_BM1370_2/BM1370-1/VDD2_1: C50.2, C51.1, U6.29 (VDD2_1)
/ASICs/ASICs_BM1370_2/BM1370-1/VDD3_0: C47.2, C48.1, U6.1 (VDD3_0)
/ASICs/ASICs_BM1370_2/BM1370-1/VDD3_1: C49.2, C50.1, U6.30 (VDD3_1)
/ASICs/ASICs_BM1370_2/BM1370-2/TEMP_N: U8.21 (TEMP_N)
/ASICs/ASICs_BM1370_2/BM1370-2/TEMP_P: U8.20 (TEMP_P)
/ASICs/ASICs_BM1370_2/BM1370-2/VDD1_0: C79.2, C80.1, U8.3 (VDD1_0)
/ASICs/ASICs_BM1370_2/BM1370-2/VDD1_1: C85.2, C86.1, U8.28 (VDD1_1)
/ASICs/ASICs_BM1370_2/BM1370-2/VDD2_0: C80.2, C81.1, U8.2 (VDD2_0)
/ASICs/ASICs_BM1370_2/BM1370-2/VDD2_1: C84.2, C85.1, U8.29 (VDD2_1)
/ASICs/ASICs_BM1370_2/BM1370-2/VDD3_0: C81.2, C82.1, U8.1 (VDD3_0)
/ASICs/ASICs_BM1370_2/BM1370-2/VDD3_1: C83.2, C84.1, U8.30 (VDD3_1)
/ASICs/ASICs_BM1370_2/BM1370-3/TEMP_N: U11.21 (TEMP_N)
/ASICs/ASICs_BM1370_2/BM1370-3/TEMP_P: U11.20 (TEMP_P)
/ASICs/ASICs_BM1370_2/BM1370-3/VDD1_0: C130.2, C131.1, U11.3 (VDD1_0)
/ASICs/ASICs_BM1370_2/BM1370-3/VDD1_1: C136.2, C137.1, U11.28 (VDD1_1)
/ASICs/ASICs_BM1370_2/BM1370-3/VDD2_0: C131.2, C132.1, U11.2 (VDD2_0)
/ASICs/ASICs_BM1370_2/BM1370-3/VDD2_1: C135.2, C136.1, U11.29 (VDD2_1)
/ASICs/ASICs_BM1370_2/BM1370-3/VDD3_0: C132.2, C133.1, U11.1 (VDD3_0)
/ASICs/ASICs_BM1370_2/BM1370-3/VDD3_1: C134.2, C135.1, U11.30 (VDD3_1)
/ASICs/ASICs_BM1370_2/BM1370-4/BO: R53.2
/ASICs/ASICs_BM1370_2/BM1370-4/CLKO: R52.2; also elsewhere on the board
/ASICs/ASICs_BM1370_2/BM1370-4/CO: R50.2
/ASICs/ASICs_BM1370_2/BM1370-4/RI: U13.24 (RI); also elsewhere on the board
/ASICs/ASICs_BM1370_2/BM1370-4/RSTO_n: U13.26 (NRSTO); also elsewhere on the board
/ASICs/ASICs_BM1370_2/BM1370-4/TEMP_N: U13.21 (TEMP_N)
/ASICs/ASICs_BM1370_2/BM1370-4/TEMP_P: U13.20 (TEMP_P)
/ASICs/ASICs_BM1370_2/BM1370-4/VDD1_0: C164.2, C165.1, U13.3 (VDD1_0)
/ASICs/ASICs_BM1370_2/BM1370-4/VDD1_1: C170.2, C171.1, U13.28 (VDD1_1)
/ASICs/ASICs_BM1370_2/BM1370-4/VDD2_0: C165.2, C166.1, U13.2 (VDD2_0)
/ASICs/ASICs_BM1370_2/BM1370-4/VDD2_1: C169.2, C170.1, U13.29 (VDD2_1)
/ASICs/ASICs_BM1370_2/BM1370-4/VDD3_0: C166.2, C167.1, U13.1 (VDD3_0)
/ASICs/ASICs_BM1370_2/BM1370-4/VDD3_1: C168.2, C169.1, U13.30 (VDD3_1)
/ASICs/ASICs_BM1370_2/BO1: U6.9 (BI); also elsewhere on the board
/ASICs/ASICs_BM1370_2/BO2: R16.2, U8.9 (BI)
/ASICs/ASICs_BM1370_2/BO3: R26.2, U11.9 (BI)
/ASICs/ASICs_BM1370_2/BO4: R43.2, U13.9 (BI)
/ASICs/ASICs_BM1370_2/CLKO1: U6.8 (CLKI); also elsewhere on the board
/ASICs/ASICs_BM1370_2/CLKO2: R15.2, U8.8 (CLKI)
/ASICs/ASICs_BM1370_2/CLKO3: R25.2, U11.8 (CLKI)
/ASICs/ASICs_BM1370_2/CLKO4: R42.2, U13.8 (CLKI)
/ASICs/ASICs_BM1370_2/CO1: U6.6 (CI); also elsewhere on the board
/ASICs/ASICs_BM1370_2/CO2: R13.2, U8.6 (CI)
/ASICs/ASICs_BM1370_2/CO3: R23.2, U11.6 (CI)
/ASICs/ASICs_BM1370_2/CO4: R40.2, U13.6 (CI)
/ASICs/ASICs_BM1370_2/RI1: R14.2; also elsewhere on the board
/ASICs/ASICs_BM1370_2/RI02: R24.2, U6.24 (RI)
/ASICs/ASICs_BM1370_2/RI3: R41.2, U8.24 (RI)
/ASICs/ASICs_BM1370_2/RI4: R51.2, U11.24 (RI)
/ASICs/ASICs_BM1370_2/RSTO1: U6.5 (NRSTI); also elsewhere on the board
/ASICs/ASICs_BM1370_2/RSTO2: U6.26 (NRSTO), U8.5 (NRSTI)
/ASICs/ASICs_BM1370_2/RSTO3: U8.26 (NRSTO), U11.5 (NRSTI)
/ASICs/ASICs_BM1370_2/RSTO4: U11.26 (NRSTO), U13.5 (NRSTI)
/CI: U5.6 (CI); also elsewhere on the board
/CLKI: U5.8 (CLKI); also elsewhere on the board
/RO: R9.2; also elsewhere on the board
/RSTIn: U5.5 (NRSTI); also elsewhere on the board
GND: C6.2, C7.2, C8.2, C9.2, C10.2, C11.1, C18.2, C19.2, C20.2, C21.2, C22.2, C23.2, C24.2, C25.2, C26.2, C27.2, C28.1, C35.2, C36.2, C37.2, C38.2, C39.2, C40.2, C41.2, C42.2, C43.2, C44.2, C45.1, C52.2, C53.2, C54.2, C55.2, C56.2, C57.2, C58.2, C59.2, C60.2, C61.2, C62.1, C69.2, C70.2, C71.2, C72.2, C73.2, C74.2, C75.2, C76.2, C77.2, C78.2, C79.1, C86.2, C87.2, C88.2, C89.2, C90.2, C91.2, C92.2, C93.2, C94.2, C95.2, C96.1, C103.2, C104.2, C105.2, C106.2, C107.2, C125.2, C126.2, C127.2, C128.2, C129.2, C130.1, C137.2, C138.2, C139.2, C140.2, C141.2, C142.2, C143.2, C144.2, C145.2, C146.2, C147.1, C154.2, C155.2, C156.2, C157.2, C158.2, C159.2, C160.2, C161.2, C162.2, C163.2, C164.1, C171.2, C172.2, C173.2, C174.2, C175.2, R7.2, R12.2, R17.2, R22.2, R27.2, R34.2, R44.2, R49.2, R54.2, U4.4 (VSS), U4.13 (PLL_VSS), U4.18 (VSS), U4.27 (VSS), U4.32 (VSS), U5.4 (VSS), U5.13 (PLL_VSS), U5.18 (VSS), U5.27 (VSS), U5.32 (VSS), U6.4 (VSS), U6.13 (PLL_VSS), U6.18 (VSS), U6.27 (VSS), U6.32 (VSS), U7.4 (VSS), U7.13 (PLL_VSS), U7.18 (VSS), U7.27 (VSS), U7.32 (VSS), U8.4 (VSS), U8.13 (PLL_VSS), U8.18 (VSS), U8.27 (VSS), U8.32 (VSS), U9.4 (VSS), U9.13 (PLL_VSS), U9.18 (VSS), U9.27 (VSS), U9.32 (VSS), U11.4 (VSS), U11.13 (PLL_VSS), U11.18 (VSS), U11.27 (VSS), U11.32 (VSS), U12.4 (VSS), U12.13 (PLL_VSS), U12.18 (VSS), U12.27 (VSS), U12.32 (VSS), U13.4 (VSS), U13.13 (PLL_VSS), U13.18 (VSS), U13.27 (VSS), U13.32 (VSS); also elsewhere on the board
unnamed: R6.1, U4.22 (BO)
unnamed: R5.1, U4.23 (CLKO)
unnamed: R3.1, U4.25 (CO)
unnamed: R7.1, U4.11 (LITE_PAD)
unnamed: R4.1, U4.7 (RO)
unnamed: R11.1, U5.22 (BO)
unnamed: R10.1, U5.23 (CLKO)
unnamed: R8.1, U5.25 (CO)
unnamed: R12.1, U5.11 (LITE_PAD)
unnamed: R9.1, U5.7 (RO)
unnamed: R16.1, U6.22 (BO)
unnamed: R15.1, U6.23 (CLKO)
unnamed: R13.1, U6.25 (CO)
unnamed: R17.1, U6.11 (LITE_PAD)
unnamed: R14.1, U6.7 (RO)
unnamed: R21.1, U7.22 (BO)
unnamed: R20.1, U7.23 (CLKO)
unnamed: R18.1, U7.25 (CO)
unnamed: R22.1, U7.11 (LITE_PAD)
unnamed: R19.1, U7.7 (RO)
unnamed: R26.1, U8.22 (BO)
unnamed: R25.1, U8.23 (CLKO)
unnamed: R23.1, U8.25 (CO)
unnamed: R27.1, U8.11 (LITE_PAD)
unnamed: R24.1, U8.7 (RO)
unnamed: R33.1, U9.22 (BO)
unnamed: R32.1, U9.23 (CLKO)
unnamed: R30.1, U9.25 (CO)
unnamed: R34.1, U9.11 (LITE_PAD)
unnamed: R31.1, U9.7 (RO)
unnamed: R43.1, U11.22 (BO)
unnamed: R42.1, U11.23 (CLKO)
unnamed: R40.1, U11.25 (CO)
unnamed: R44.1, U11.11 (LITE_PAD)
unnamed: R41.1, U11.7 (RO)
unnamed: R48.1, U12.22 (BO)
unnamed: R47.1, U12.23 (CLKO)
unnamed: R45.1, U12.25 (CO)
unnamed: R49.1, U12.11 (LITE_PAD)
unnamed: R46.1, U12.7 (RO)
unnamed: R53.1, U13.22 (BO)
unnamed: R52.1, U13.23 (CLKO)
unnamed: R50.1, U13.25 (CO)
unnamed: R54.1, U13.11 (LITE_PAD)
unnamed: R51.1, U13.7 (RO)
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

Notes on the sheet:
low ESR
PIN_MODE = 0 : mode 0 PIN_MODE = 1 : mode 1 pull up interne

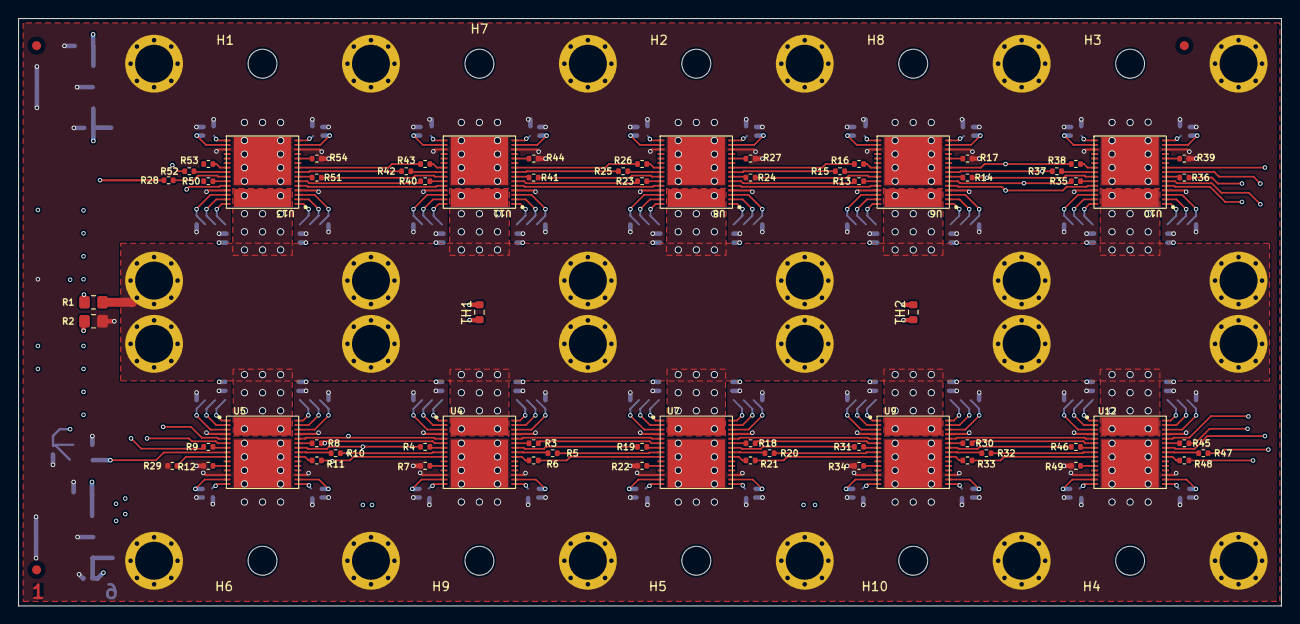
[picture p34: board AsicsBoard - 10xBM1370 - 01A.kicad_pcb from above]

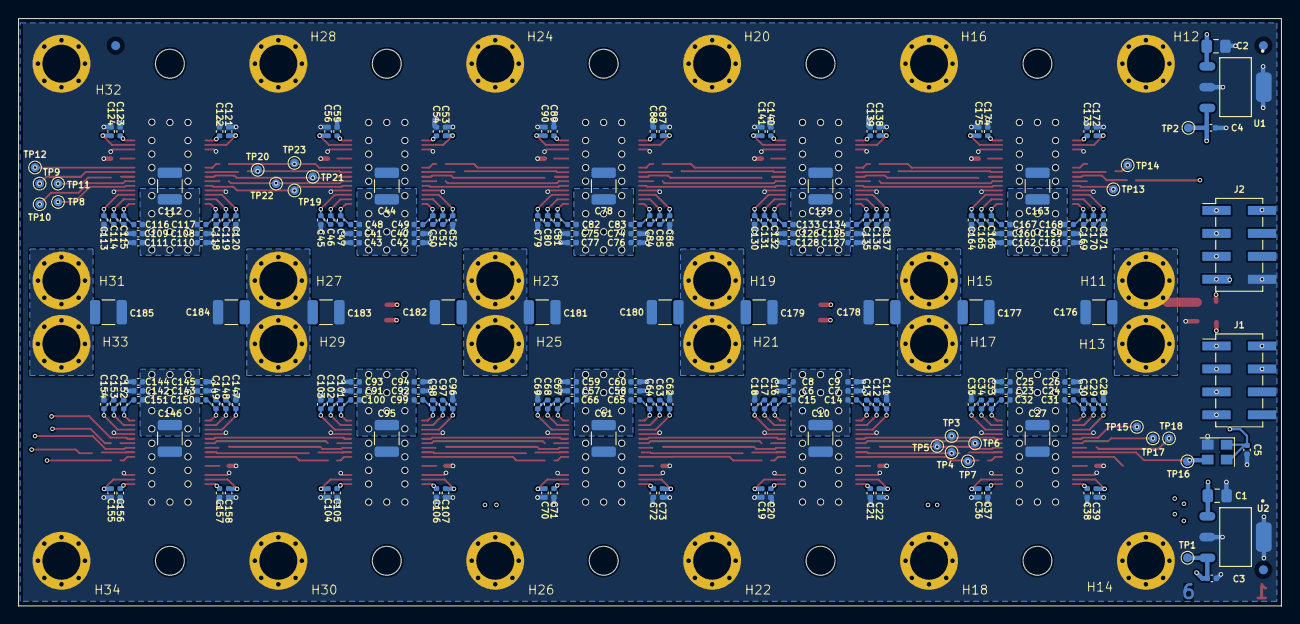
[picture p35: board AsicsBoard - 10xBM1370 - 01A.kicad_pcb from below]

Board: 6 copper layers, 139.8 x 65.0 mm, 319 parts (240 on the bottom side), 174 nets.

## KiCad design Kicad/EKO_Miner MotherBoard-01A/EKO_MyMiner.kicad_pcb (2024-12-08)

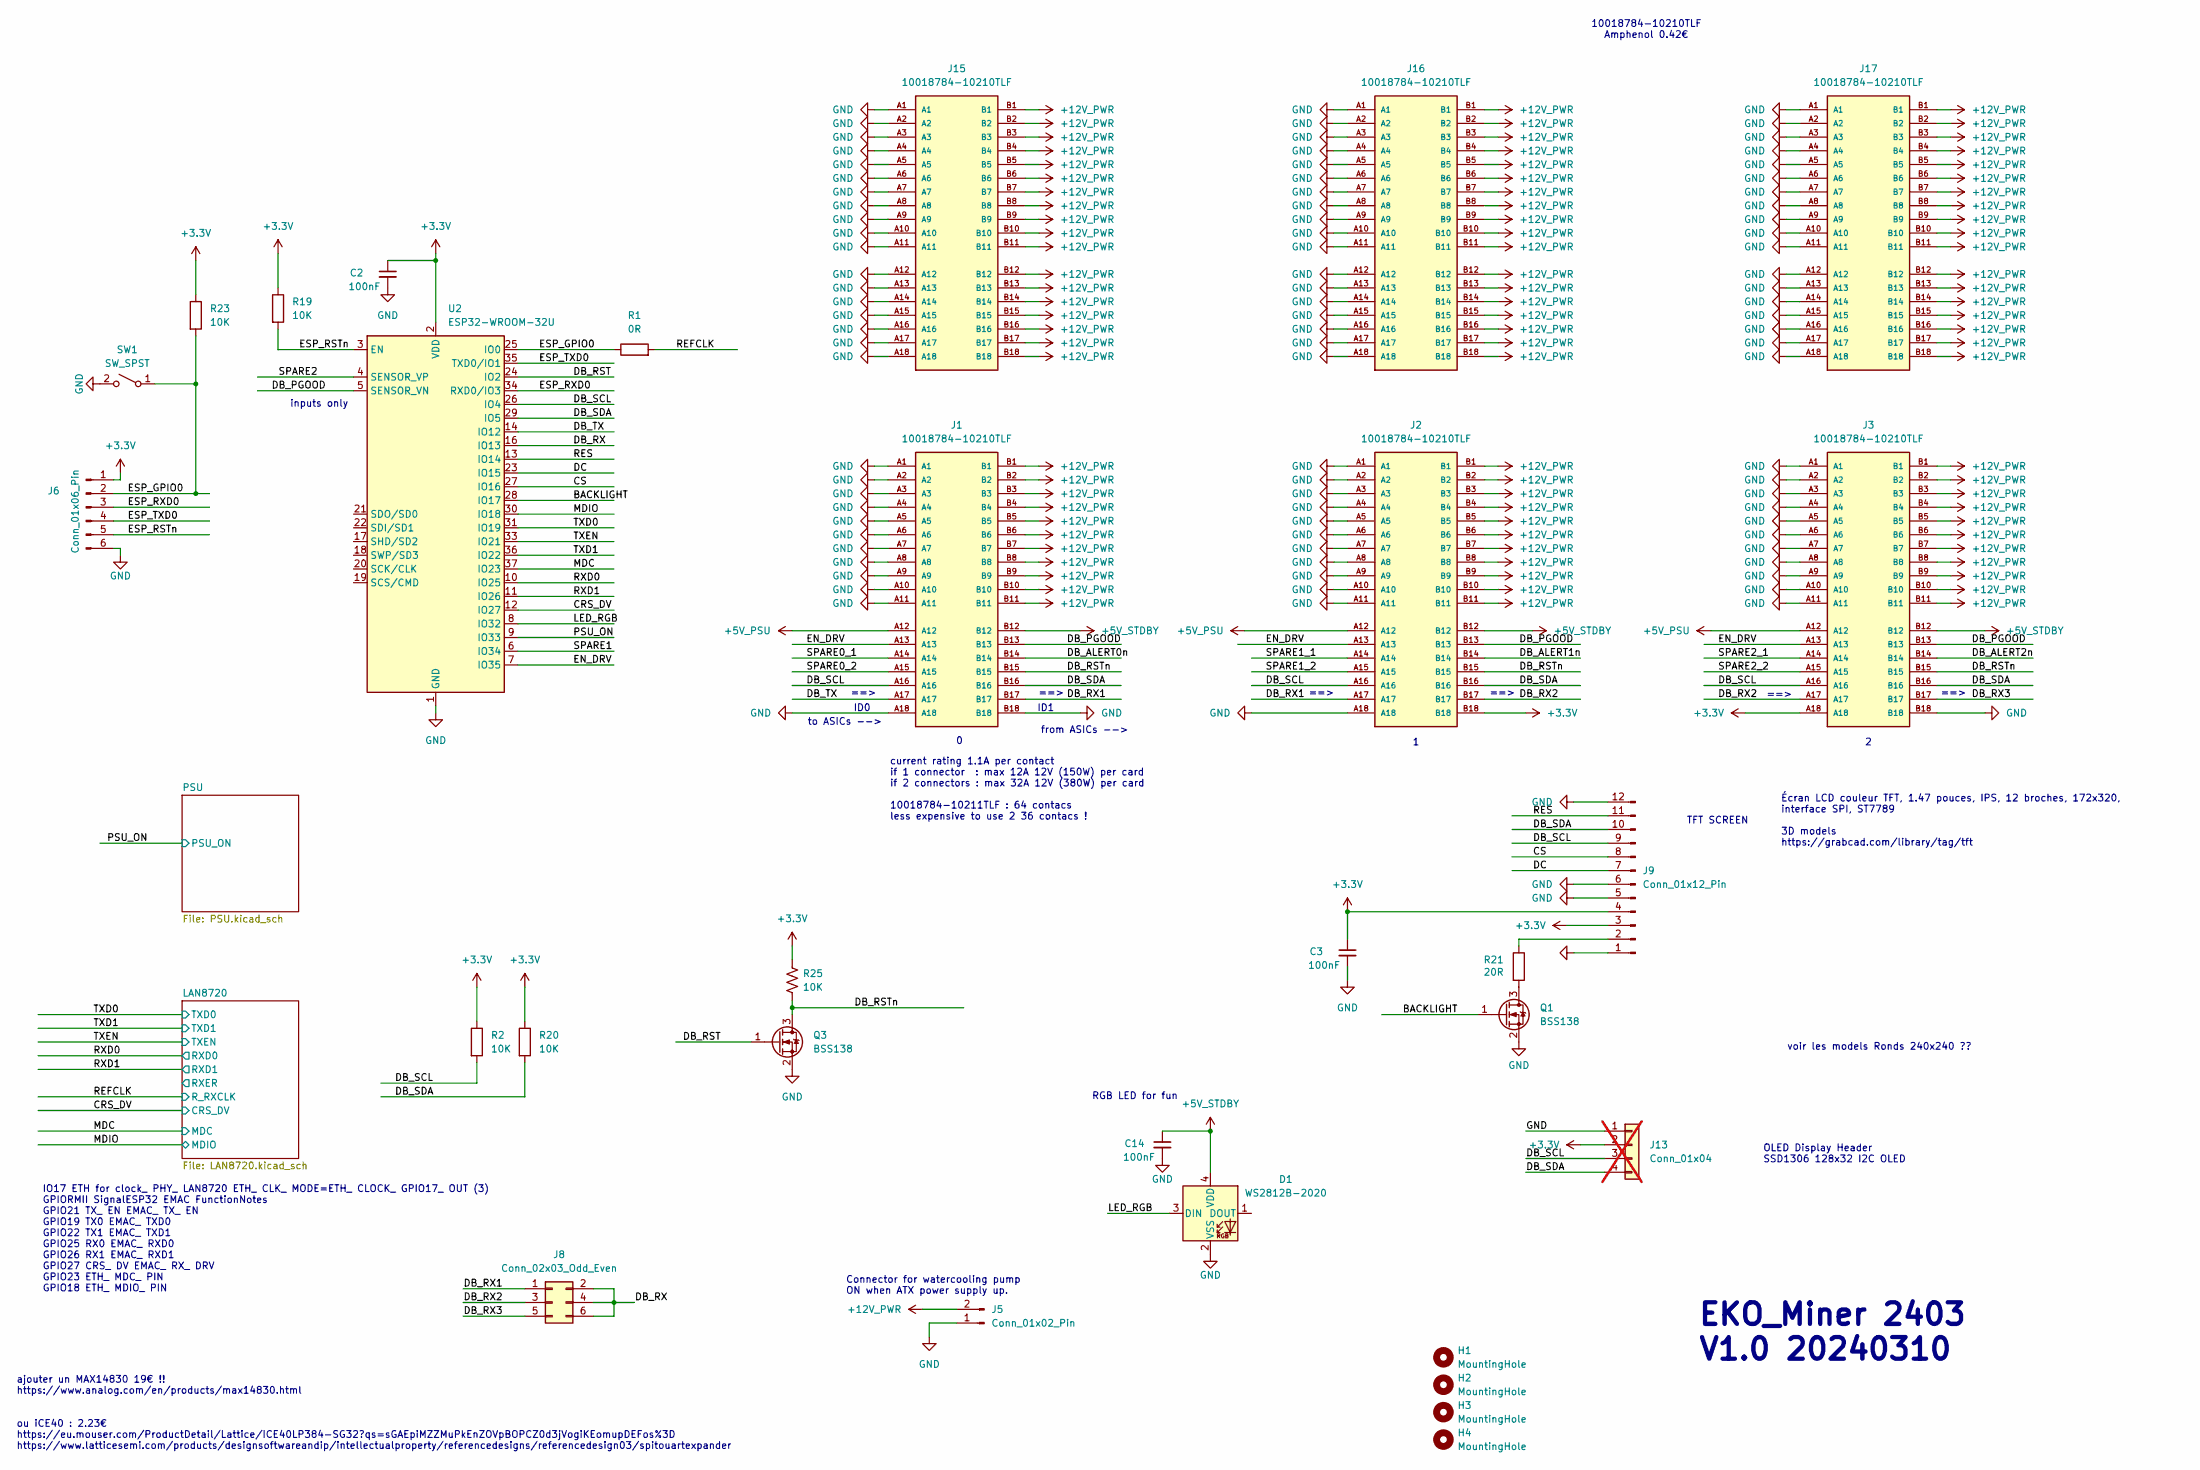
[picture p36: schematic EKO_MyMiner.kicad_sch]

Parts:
C2, C3, C14: 100nF; C_0603_1608Metric
D1: WS2812B-2020; WS2812B2020
H1, H2, H3, H4: MountingHole; MountingHole_3.2mm_M3_DIN965_Pad
J1, J2, J3, J15, J16, J17: 10018784-10210TLF; AMPHENOL_10018784-10210TLF; PARTREV S
J5: Conn_01x02_Pin; JST_EH_B2B-EH-A_1x02_P2.50mm_Vertical
J6: Conn_01x06_Pin; EKO_ESP_ISP
J8: Conn_02x03_Odd_Even; PinHeader_2x03_P2.54mm_Vertical
J9: Conn_01x12_Pin; LCD LBS147TC-IG01
J13: Conn_01x04; PinHeader_1x04_P2.54mm_Vertical; not fitted
Q1, Q3: BSS138; SOT-23
R1: 0R; R_0603_1608Metric
R2, R19, R20, R23: 10K; R_0603_1608Metric
R21: 20R; R_0603_1608Metric
R25: 10K; R_0402_1005Metric; PARTNO RC0402JR-0710KL
SW1: SW_SPST; SW_PUSH_6mm_H9.5mm
U2: ESP32-WROOM-32U

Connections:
+3.3V: C2.1, C3.1, J2.B18, J3.A18, J6.1, J9.3, J9.4, J13.2, R2.1, R19.1, R20.1, R23.1, R25.2, U2.2 (VDD); also elsewhere on the board
+5V_PSU: J1.A12, J2.A12, J3.A12; also elsewhere on the board
+5V_STDBY: C14.1, D1.4 (VDD), J1.B12, J2.B12, J3.B12; also elsewhere on the board
+12V_PWR: J1.B1, J1.B2, J1.B3, J1.B4, J1.B5, J1.B6, J1.B7, J1.B8, J1.B9, J1.B10, J1.B11, J2.B1, J2.B2, J2.B3, J2.B4, J2.B5, J2.B6, J2.B7, J2.B8, J2.B9, J2.B10, J2.B11, J3.B1, J3.B2, J3.B3, J3.B4, J3.B5, J3.B6, J3.B7, J3.B8, J3.B9, J3.B10, J3.B11, J5.2, J15.B1, J15.B2, J15.B3, J15.B4, J15.B5, J15.B6, J15.B7, J15.B8, J15.B9, J15.B10, J15.B11, J15.B12, J15.B13, J15.B14, J15.B15, J15.B16, J15.B17, J15.B18, J16.B1, J16.B2, J16.B3, J16.B4, J16.B5, J16.B6, J16.B7, J16.B8, J16.B9, J16.B10, J16.B11, J16.B12, J16.B13, J16.B14, J16.B15, J16.B16, J16.B17, J16.B18, J17.B1, J17.B2, J17.B3, J17.B4, J17.B5, J17.B6, J17.B7, J17.B8, J17.B9, J17.B10, J17.B11, J17.B12, J17.B13, J17.B14, J17.B15, J17.B16, J17.B17, J17.B18; also elsewhere on the board
/BACKLIGHT: Q1.1 (G), U2.28 (IO17)
/CRS_DV: U2.12 (IO27); also elsewhere on the board
/CS: J9.8, U2.27 (IO16)
/DB_ALERT0n: J1.B14
/DB_ALERT1n: J2.B14
/DB_ALERT2n: J3.B14
/DB_PGOOD: J1.B13, J2.B13, J3.B13, U2.5 (SENSOR_VN)
/DB_RST: Q3.1 (G), U2.24 (IO2)
/DB_RSTn: J1.B15, J2.B15, J3.B15, Q3.3 (D), R25.1
/DB_RX: J8.2, J8.4, J8.6, U2.16 (IO13)
/DB_RX1: J1.B17, J2.A17, J8.1
/DB_RX2: J2.B17, J3.A17, J8.3
/DB_RX3: J3.B17, J8.5
/DB_SCL: J1.A16, J2.A16, J3.A16, J9.9, J13.3, R2.2, U2.26 (IO4)
/DB_SDA: J1.B16, J2.B16, J3.B16, J9.10, J13.4, R20.2, U2.29 (IO5)
/DB_TX: J1.A17, U2.14 (IO12)
/DC: J9.7, U2.23 (IO15)
/EN_DRV: J1.A13, J2.A13, J3.A13, U2.7 (IO35)
/ESP_GPIO0: J6.2, R1.1, R23.2, SW1.1 (A), U2.25 (IO0)
/ESP_RSTn: J6.5, R19.2, U2.3 (EN)
/ESP_RXD0: J6.3, U2.34 (RXD0/IO3)
/ESP_TXD0: J6.4, U2.35 (TXD0/IO1)
/LED_RGB: D1.3 (DIN), U2.8 (IO32)
/MDC: U2.37 (IO23); also elsewhere on the board
/MDIO: U2.30 (IO18); also elsewhere on the board
/PSU_ON: U2.9 (IO33); also elsewhere on the board
/REFCLK: R1.2; also elsewhere on the board
/RES: J9.11, U2.13 (IO14)
/RXD0: U2.10 (IO25); also elsewhere on the board
/RXD1: U2.11 (IO26); also elsewhere on the board
/SPARE0_1: J1.A14
/SPARE0_2: J1.A15
/SPARE1: U2.6 (IO34)
/SPARE1_1: J2.A14
/SPARE1_2: J2.A15
/SPARE2: U2.4 (SENSOR_VP)
/SPARE2_1: J3.A14
/SPARE2_2: J3.A15
/TXD0: U2.31 (IO19); also elsewhere on the board
/TXD1: U2.36 (IO22); also elsewhere on the board
/TXEN: U2.33 (IO21); also elsewhere on the board
GND: C2.2, C3.2, C14.2, D1.2 (VSS), J1.A1, J1.A2, J1.A3, J1.A4, J1.A5, J1.A6, J1.A7, J1.A8, J1.A9, J1.A10, J1.A11, J1.A18, J1.B18, J2.A1, J2.A2, J2.A3, J2.A4, J2.A5, J2.A6, J2.A7, J2.A8, J2.A9, J2.A10, J2.A11, J2.A18, J3.A1, J3.A2, J3.A3, J3.A4, J3.A5, J3.A6, J3.A7, J3.A8, J3.A9, J3.A10, J3.A11, J3.B18, J5.1, J6.6, J9.1, J9.5, J9.6, J9.12, J13.1, J15.A1, J15.A2, J15.A3, J15.A4, J15.A5, J15.A6, J15.A7, J15.A8, J15.A9, J15.A10, J15.A11, J15.A12, J15.A13, J15.A14, J15.A15, J15.A16, J15.A17, J15.A18, J16.A1, J16.A2, J16.A3, J16.A4, J16.A5, J16.A6, J16.A7, J16.A8, J16.A9, J16.A10, J16.A11, J16.A12, J16.A13, J16.A14, J16.A15, J16.A16, J16.A17, J16.A18, J17.A1, J17.A2, J17.A3, J17.A4, J17.A5, J17.A6, J17.A7, J17.A8, J17.A9, J17.A10, J17.A11, J17.A12, J17.A13, J17.A14, J17.A15, J17.A16, J17.A17, J17.A18, Q1.2 (S), Q3.2 (S), SW1.2 (B), U2.1 (GND), U2.15 (GND), U2.38 (GND), U2.39 (GND); also elsewhere on the board
unnamed: J9.2, R21.1
unnamed: Q1.3 (D), R21.2

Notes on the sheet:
to ASICs -->
current rating 1.1A per contact if 1 connector : max 12A 12V (150W) per card if 2 connectors : max 32A 12V (380W) per card 10018784-10211TLF : 64 contacs less expensive to use 2 36 contacs !
10018784-10210TLF Amphenol 0.42€
voir les models Ronds 240x240 ??
TFT SCREEN
==>
ajouter un MAX14830 19€ !! https://www.analog.com/en/products/max14830.html ou iCE40 : 2.23€ https://eu.mouser.com/ProductDetail/Lattice/ICE40LP384-SG32?qs=sGAEpiMZZMuPkEnZOVpBOPCZ0d3jVogiKEomupDEFos%3D https://www.latticesemi.com/products/designsoftwareandip/intellectualproperty/referencedesigns/r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
OLED Display Header SSD1306 128x32 I2C OLED
Connector for watercooling pump ON when ATX power supply up.
ID0
Écran LCD couleur TFT, 1.47 pouces, IPS, 12 broches, 172x320, interface SPI, ST7789 3D models https://grabcad.com/library/tag/tft
inputs only
IO17 ETH for clock_ PHY_ LAN8720 ETH_ CLK_ MODE=ETH_ CLOCK_ GPIO17_ OUT (3) GPIORMII SignalESP32 EMAC FunctionNotes GPIO21 TX_ EN EMAC_ TX_ EN GPIO19 TX0 EMAC_ TXD0 GPIO22 TX1 EMAC_ TXD1 GPIO25 RX0 EMAC_ RXD0 GPIO26 RX1 EMAC_ RXD1 GPIO27 CRS_ DV EMAC_ RX_ DRV GPIO23 ETH_ MDC_ PIN GPIO18 ETH_ MDIO_ 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
from ASICs -->
RGB LED for fun
ID1
EKO_Miner 2403 V1.0 20240310

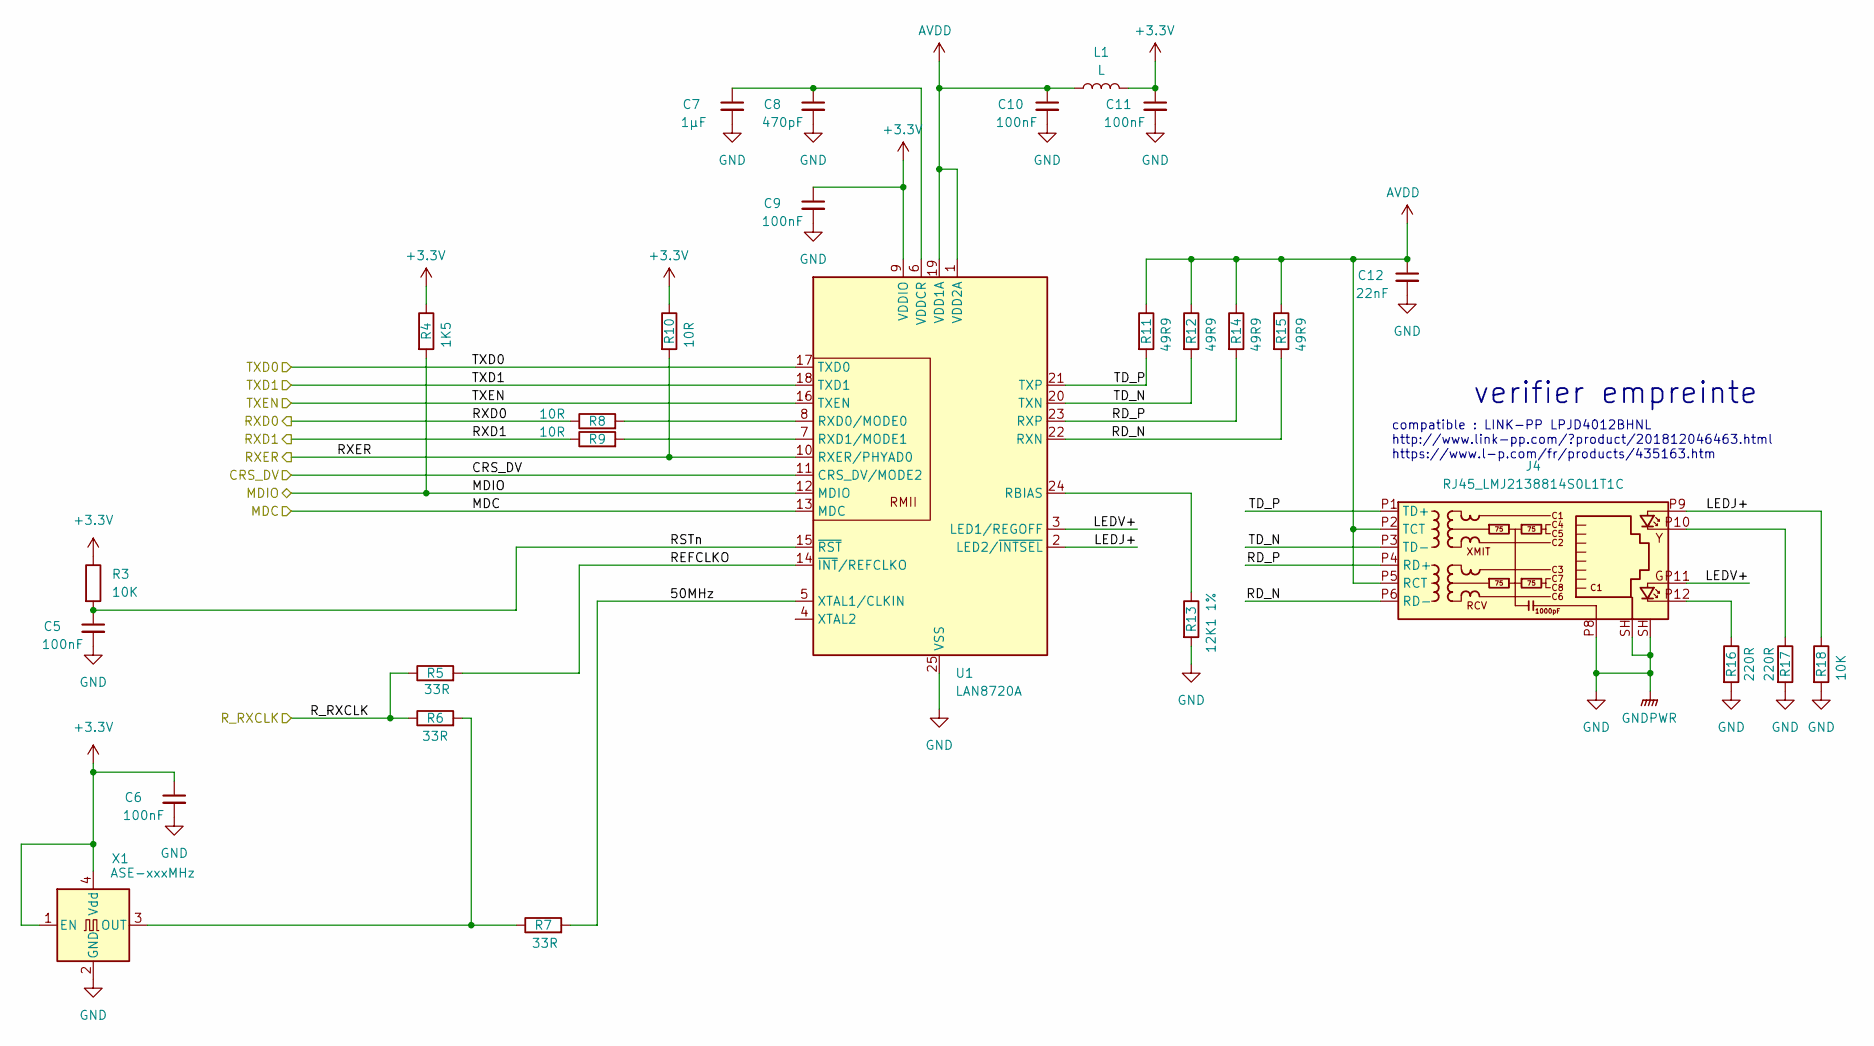
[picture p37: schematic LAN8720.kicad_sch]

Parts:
C5, C6, C9, C10, C11: 100nF; C_0603_1608Metric
C7: 1µF; C_0603_1608Metric
C8: 470pF; C_0603_1608Metric
C12: 22nF; C_0603_1608Metric
J4: RJ45_LMJ2138814S0L1T1C; LMJ2138814SOL1T1C
L1: L; L_0805_2012Metric
R3, R18: 10K; R_0603_1608Metric
R4: 1K5; R_0603_1608Metric
R5, R6, R7: 33R; R_0603_1608Metric
R8, R9, R10: 10R; R_0603_1608Metric
R11, R12, R14, R15: 49R9; R_0603_1608Metric
R13: 12K1 1%; R_0603_1608Metric
R16, R17: 220R; R_0603_1608Metric
U1: LAN8720A; LAN8720_VQFN-24-1EP_4x4mm_P0.5mm_EP2.5x2.5mm_ThermalVias
X1: ASE-xxxMHz; Oscillator_SMD_Abracon_ASE-4Pin_3.2x2.5mm

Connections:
+3.3V: C6.1, C9.1, C11.1, L1.2, R3.1, R4.1, R10.1, U1.9 (VDDIO), X1.1 (EN), X1.4 (Vdd); also elsewhere on the board
/CRS_DV: U1.11 (CRS_DV/MODE2); also elsewhere on the board
/LAN8720/50MHz: R7.2, U1.5 (XTAL1/CLKIN)
/LAN8720/LEDJ+: J4.P9, R18.1, U1.2 (LED2/~INTSEL)
/LAN8720/LEDV+: J4.P11, U1.3 (LED1/REGOFF)
/LAN8720/RD_N: J4.P6 (RD-), R15.2, U1.22 (RXN)
/LAN8720/RD_P: J4.P4 (RD+), R14.2, U1.23 (RXP)
/LAN8720/REFCLKO: R5.2, U1.14 (~INT/REFCLKO)
/LAN8720/RSTn: C5.1, R3.2, U1.15 (~RST)
/LAN8720/RXER: R10.2, U1.10 (RXER/PHYAD0)
/LAN8720/TD_N: J4.P3 (TD-), R12.2, U1.20 (TXN)
/LAN8720/TD_P: J4.P1 (TD+), R11.2, U1.21 (TXP)
/MDC: U1.13 (MDC); also elsewhere on the board
/MDIO: R4.2, U1.12 (MDIO); also elsewhere on the board
/REFCLK: R5.1, R6.1; also elsewhere on the board
/RXD0: R8.1; also elsewhere on the board
/RXD1: R9.1; also elsewhere on the board
/TXD0: U1.17 (TXD0); also elsewhere on the board
/TXD1: U1.18 (TXD1); also elsewhere on the board
/TXEN: U1.16 (TXEN); also elsewhere on the board
AVDD: C10.1, C12.1, J4.P2 (TCT), J4.P5 (RCT), L1.1, R11.1, R12.1, R14.1, R15.1, U1.1 (VDD2A), U1.19 (VDD1A)
GND: C5.2, C6.2, C7.2, C8.2, C9.2, C10.2, C11.2, C12.2, J4.P8, J4.SH, R13.2, R16.2, R17.2, R18.2, U1.25 (VSS), X1.2 (GND); also elsewhere on the board
unnamed: J4.P10, R17.1
unnamed: J4.P12, R16.1
unnamed: R13.1, U1.24 (RBIAS)
unnamed: R8.2, U1.8 (RXD0/MODE0)
unnamed: R9.2, U1.7 (RXD1/MODE1)
unnamed: C7.1, C8.1, U1.6 (VDDCR)
unnamed: R6.2, R7.1, X1.3 (OUT)

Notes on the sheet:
compatible : LINK-PP LPJD4012BHNL http://www.link-pp.com/?product/201812046463.html https://www.l-p.com/fr/products/435163.htm
verifier empreinte

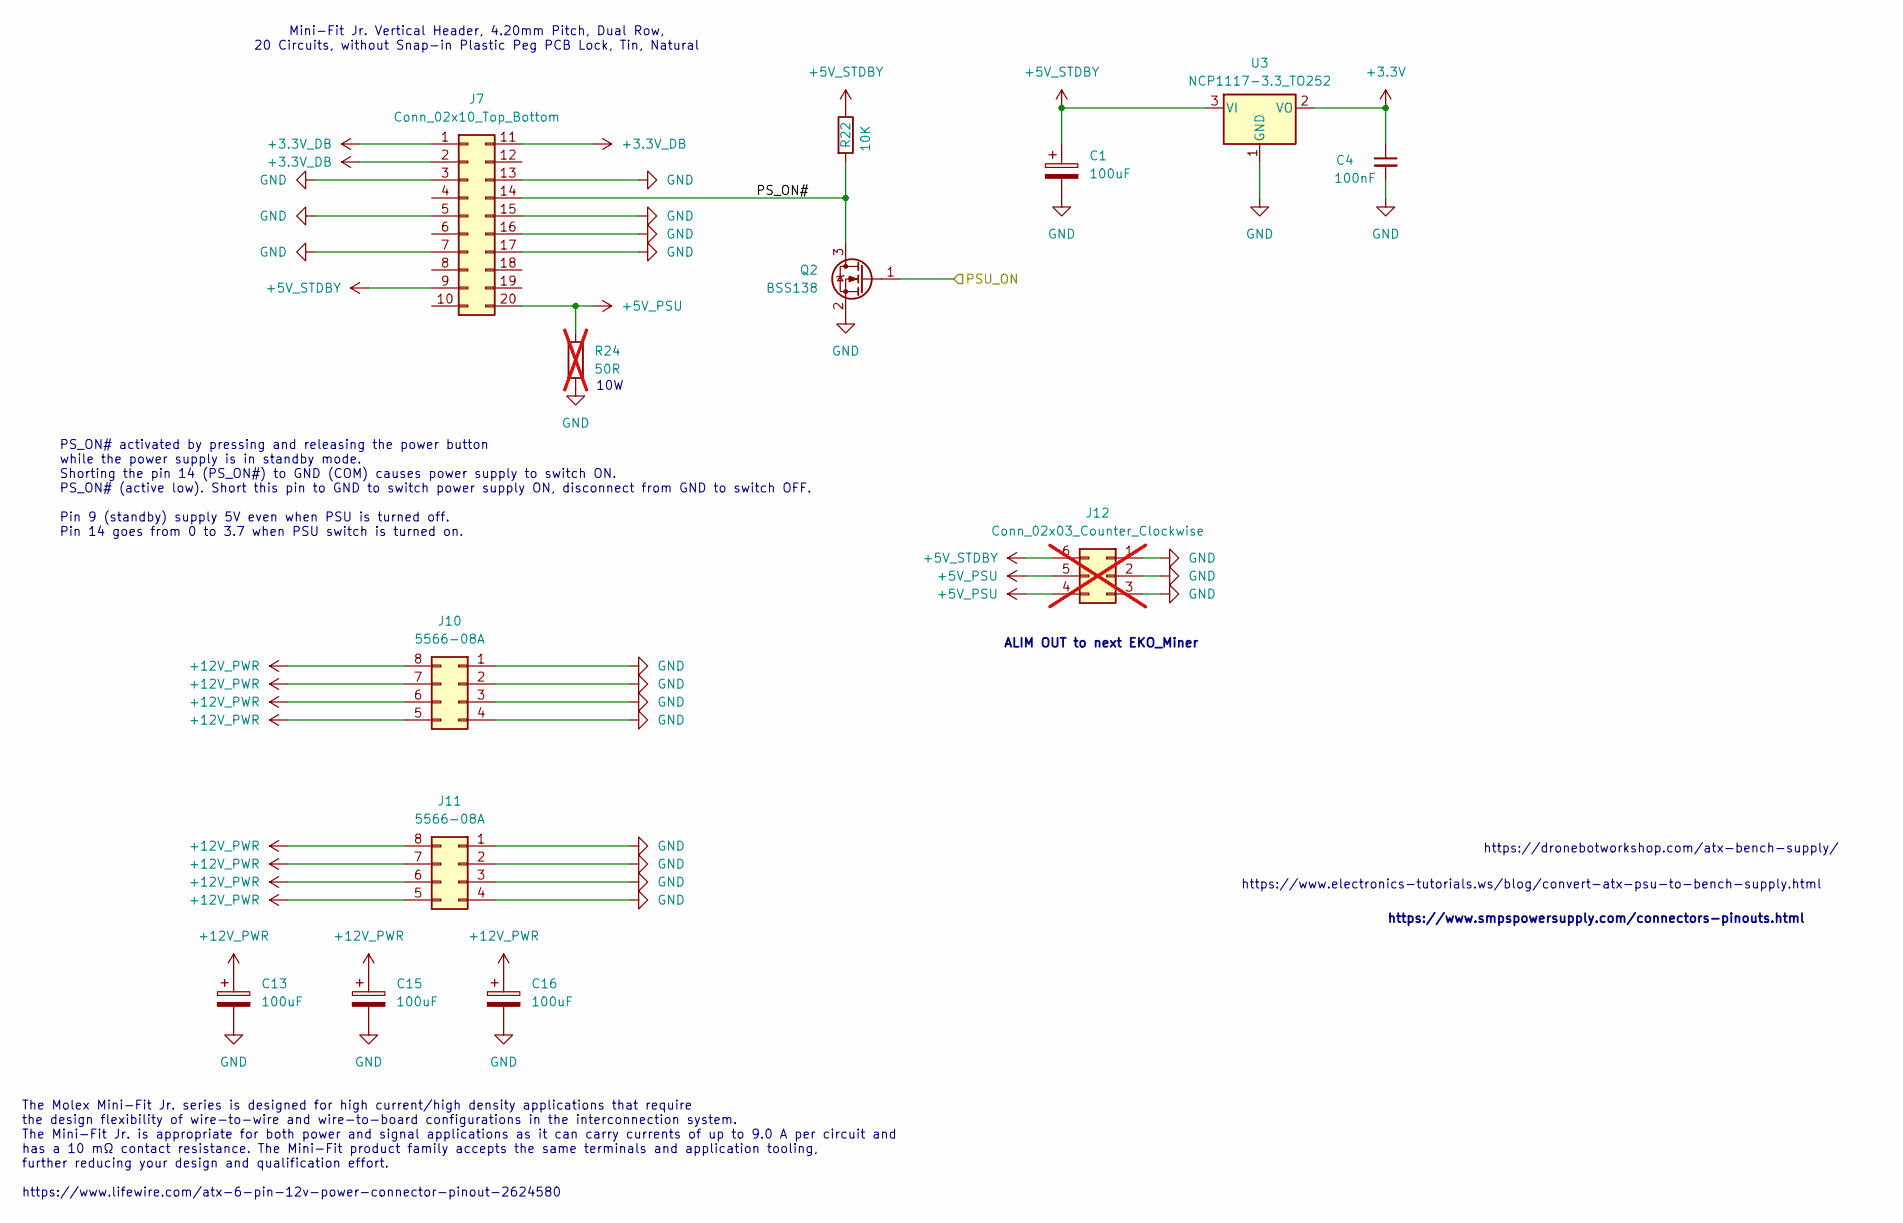
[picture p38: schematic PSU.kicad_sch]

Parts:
C1, C13, C15, C16: 100uF; CP_Elec_5x5.7
C4: 100nF; C_0603_1608Metric
J7: Conn_02x10_Top_Bottom; Molex_Mini-Fit_Jr_5566-20A_2x10_P4.20mm_Vertical
J10, J11: 5566-08A; Molex_Mini-Fit_Jr_5566-08A2_2x04_P4.20mm_Vertical
J12: Conn_02x03_Counter_Clockwise; Molex_Mini-Fit_Jr_5566-06A2_2x03_P4.20mm_Vertical; not fitted
Q2: BSS138; SOT-23
R22: 10K; R_0603_1608Metric
R24: 50R; R_Axial_Power_L25.0mm_W6.4mm_P27.94mm; not fitted
U3: NCP1117-3.3_TO252; TO-252-2

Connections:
+3.3V: C4.1, U3.2 (VO); also elsewhere on the board
+3.3V_DB: J7.1, J7.2, J7.11
+5V_PSU: J7.20, J12.4, J12.5, R24.1; also elsewhere on the board
+5V_STDBY: C1.1, J7.9, J12.6, R22.1, U3.3 (VI); also elsewhere on the board
+12V_PWR: C13.1, C15.1, C16.1, J10.5, J10.6, J10.7, J10.8, J11.5, J11.6, J11.7, J11.8; also elsewhere on the board
/PSU/PS_ON#: J7.14, Q2.3 (D), R22.2
/PSU_ON: Q2.1 (G); also elsewhere on the board
GND: C1.2, C4.2, C13.2, C15.2, C16.2, J7.3, J7.5, J7.7, J7.13, J7.15, J7.16, J7.17, J10.1, J10.2, J10.3, J10.4, J11.1, J11.2, J11.3, J11.4, J12.1, J12.2, J12.3, Q2.2 (S), R24.2, U3.1 (GND); also elsewhere on the board

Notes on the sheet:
The Molex Mini-Fit Jr. series is designed for high current/high density applications that require the design flexibility of wire-to-wire and wire-to-board configurations in the interconnection system. The Mini-Fit Jr. is appropriate for both power and signal applications as it can carry currents of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
https://www.smpspowersupply.com/connectors-pinouts.html
https://dronebotworkshop.com/atx-bench-supply/
Mini-Fit Jr. Vertical Header, 4.20mm Pitch, Dual Row, 20 Circuits, without Snap-in Plastic Peg PCB Lock, Tin, Natural
PS_ON# activated by pressing and releasing the power button while the power supply is in standby mode. Shorting the pin 14 (PS_ON#) to GND (COM) causes power supply to switch ON. PS_ON# (active low). Short this pin to GND to switch power supply ON, disconnect from GND to switch OFF. Pin 9 (standby)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
https://www.electronics-tutorials.ws/blog/convert-atx-psu-to-bench-supply.html
10W
ALIM OUT to next EKO_Miner

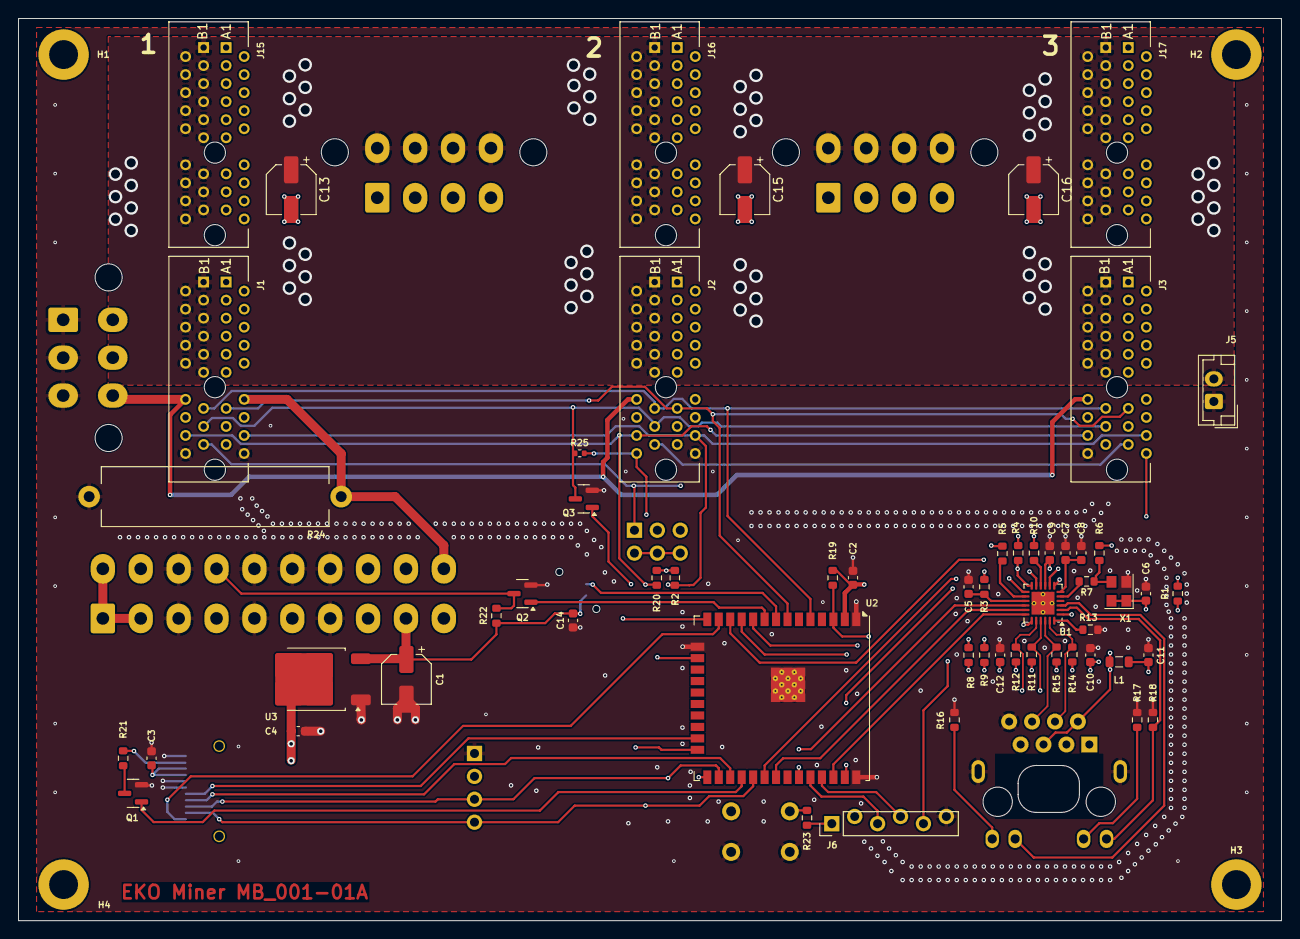
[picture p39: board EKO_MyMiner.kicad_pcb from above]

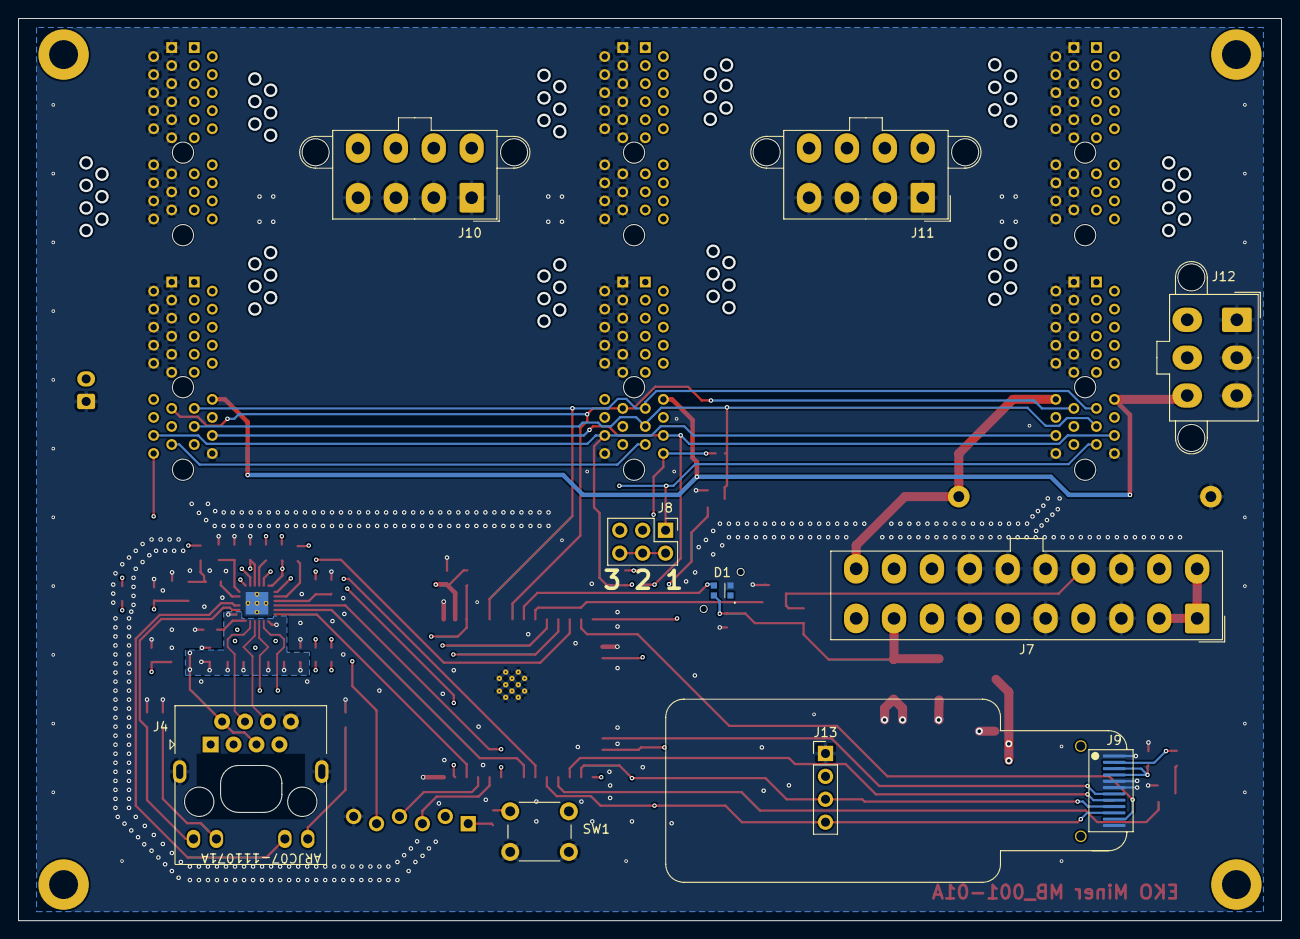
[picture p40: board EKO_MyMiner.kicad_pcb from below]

Board: 4 copper layers, 140.0 x 100.0 mm, 71 parts (10 on the bottom side), 57 nets.

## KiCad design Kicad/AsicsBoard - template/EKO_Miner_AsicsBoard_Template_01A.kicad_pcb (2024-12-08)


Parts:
C1, C2, C3, C4: 1uF; C_0805_2012Metric_Pad1.18x1.45mm_HandSolder
C5: 100nF; C_0805_2012Metric_Pad1.18x1.45mm_HandSolder
J1, J2: Conn_02x04_Odd_Even; PinHeader_2x04_P2.54mm_Vertical_SMD
R1, R2: 51R 0.5%; R_0805_2012Metric_Pad1.20x1.40mm_HandSolder
TH1, TH2: TBD; R_1206_3216Metric_Pad1.30x1.75mm_HandSolder
TP1, TP2: TestPoint; TestPoint_Pad_D1.0mm
U1: MCP1826S-1202E_DB; MCP1826S
U2: MCP1826S-0802E_DB; MCP1826S
U3: 25MHz; Oscillator_SMD_Abracon_ASE-4Pin_3.2x2.5mm

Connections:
+0.8V: C3.1, TP1.1, U2.3 (VOUT)
+1.2V: C4.1, C5.1, TP2.1, U1.3 (VOUT), U3.1 (EN), U3.4 (VIN)
+5V_STDBY: C1.1, C2.1, J1.2, U1.1 (VIN), U2.1 (VIN)
/CI: J1.3; also elsewhere on the board
/CLKI: U3.3 (OUT); also elsewhere on the board
/CTN1: J2.5, TH1.1
/CTN1_RTN: J2.7, TH1.2
/CTN2: J2.1, TH2.1
/CTN2_RTN: J2.3, TH2.2
/DB_SCL: J1.4
/DB_SDA: J1.6
/RO: J1.5; also elsewhere on the board
/RSTIn: J1.1; also elsewhere on the board
/VSN: J2.4, R2.2
/VSP: J2.2, R1.2
GND: C1.2, C2.2, C3.2, C4.2, C5.2, J1.7, J1.8, R2.1, U1.2 (GND_(TAB)), U1.4 (GND_(TAB)_2), U2.2 (GND_(TAB)), U2.4 (GND_(TAB)_2), U3.2 (GND); also elsewhere on the board
VPWR_ASIC: R1.1; also elsewhere on the board

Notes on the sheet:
+5V_STDBY : always available +5V_PSU : available when POWER is ON
25MHz ASIC clock oscillator
choisir version ajustable 1.8V / 1.2V ...


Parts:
H1, H2, H3, H4, H5, H6: MountingHole; MountingHole_3.2mm_M3_ISO7380
H7, H8, H9, H10, H11, H12, H13, H14, H15, H16, H17, H18, H19, H20, H21, H22, H23, H24, H25, H26, H27, H28, H29, H30: MountingHole_Pad; SMTSO-M3-3ET

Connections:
GND: H8.1, H10.1, H12.1, H14.1, H16.1, H18.1, H20.1, H22.1, H24.1, H26.1, H28.1, H30.1; also elsewhere on the board
VPWR_ASIC: H7.1, H9.1, H11.1, H13.1, H15.1, H17.1, H19.1, H21.1, H23.1, H25.1, H27.1, H29.1; also elsewhere on the board

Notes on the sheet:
Cooler fix
bar bus power


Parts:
TP3, TP4, TP5, TP6: TestPoint; TestPoint_Pad_D1.0mm

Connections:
/CI: TP5.1; also elsewhere on the board
/CLKI: TP4.1; also elsewhere on the board
/RO: TP6.1; also elsewhere on the board
/RSTIn: TP3.1; also elsewhere on the board

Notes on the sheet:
<-- from ASICs
to ASICs -->

Board: 6 copper layers, 50 parts (42 on the bottom side), 15 nets, no tracks yet.

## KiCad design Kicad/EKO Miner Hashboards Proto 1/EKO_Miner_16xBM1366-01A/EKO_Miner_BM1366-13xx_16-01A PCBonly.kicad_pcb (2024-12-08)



Board: 6 copper layers, 148.4 x 99.8 mm, 49 parts (41 on the bottom side), 3 nets.

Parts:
C26, C43, C60, C77, C94, C111, C128, C145, C187, C197, C207, C217, C237, C254, C271, C288, C305, C322, C339, C356: 330uF; CP_EIA-7343-31_Kemet-D_Pad2.25x2.55mm_HandSolder
C365, C366, C367, C368, C369, C370, C371, C372, C373, C374, C375, C376, C377, C378, C379, C380: 100uF; C_1210_3225Metric
H1, H2, H3, H4, H5, H6: MountingHole; MountingHole_3.2mm_M3_ISO7380
H7, H8, H11, H12: MountingHole_Pad; SMTSO-M3-3ET
J1, J2: 10018784-10210TLF; BUS_PCIexpress_x1
TP10: TestPoint; TestPoint_Pad_D1.0mm

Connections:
+12V_PWR: J1.B1, J1.B2, J1.B3, J1.B4, J1.B5, J1.B6, J1.B7, J1.B8, J1.B9, J1.B10, J1.B11, J1.B12, J1.B13, J1.B14, J1.B15, J1.B16, J1.B17, J1.B18, J2.B1, J2.B2, J2.B3, J2.B4, J2.B5, J2.B6, J2.B7, J2.B8, J2.B9, J2.B10, J2.B11
GND: C26.2, C43.2, C60.2, C77.2, C94.2, C111.2, C128.2, C145.2, C187.2, C197.2, C207.2, C217.2, C237.2, C254.2, C271.2, C288.2, C305.2, C322.2, C339.2, C356.2, C365.2, C366.2, C367.2, C368.2, C369.2, C370.2, C371.2, C372.2, C373.2, C374.2, C375.2, C376.2, C377.2, C378.2, C379.2, C380.2, J1.A1, J1.A2, J1.A3, J1.A4, J1.A5, J1.A6, J1.A7, J1.A8, J1.A9, J1.A10, J1.A11, J1.A12, J1.A13, J1.A14, J1.A15, J1.A16, J1.A17, J1.A18, J2.A1, J2.A2, J2.A3, J2.A4, J2.A5, J2.A6, J2.A7, J2.A8, J2.A9, J2.A10, J2.A11
VPWR_ASIC: C26.1, C43.1, C60.1, C77.1, C94.1, C111.1, C128.1, C145.1, C187.1, C197.1, C207.1, C217.1, C237.1, C254.1, C271.1, C288.1, C305.1, C322.1, C339.1, C356.1, C365.1, C366.1, C367.1, C368.1, C369.1, C370.1, C371.1, C372.1, C373.1, C374.1, C375.1, C376.1, C377.1, C378.1, C379.1, C380.1, H7.1, H8.1, H11.1, H12.1

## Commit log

2024-12-08 first release
    [ASICs.kicad_sch, ASICs_BM1366.kicad_sch, ASICs_BM1368.kicad_sch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]
2024-12-09 update Hashboard 1368
    [BM1368.kicad_sch, FIXs.kicad_sch]
